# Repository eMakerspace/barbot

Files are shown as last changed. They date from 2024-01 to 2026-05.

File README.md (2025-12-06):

View this project on [CADLAB.io](https://cadlab.io/project/29307). 

# eMakerspace-BarBot

Design your own drinks...
- Use a WordPress configurator to design a drink
- Pay the drink with Twint
- Grab the data with a python script over the WooCommerce API
- Control the robot via the RPi HAT and make the drinks

## Web UI
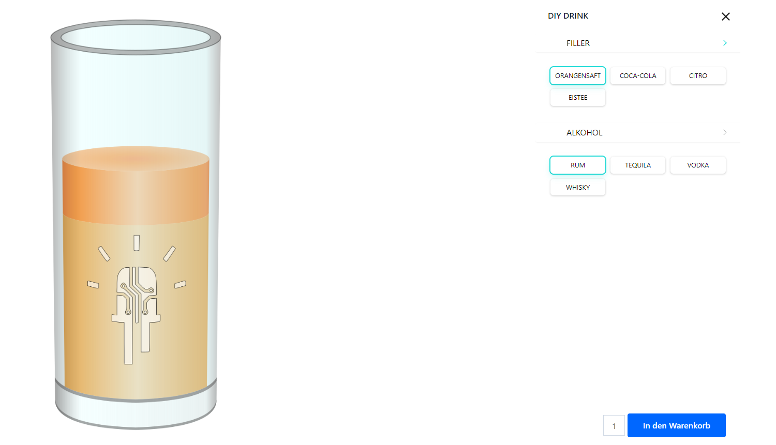
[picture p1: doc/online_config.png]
Configurator


## RPi HAT

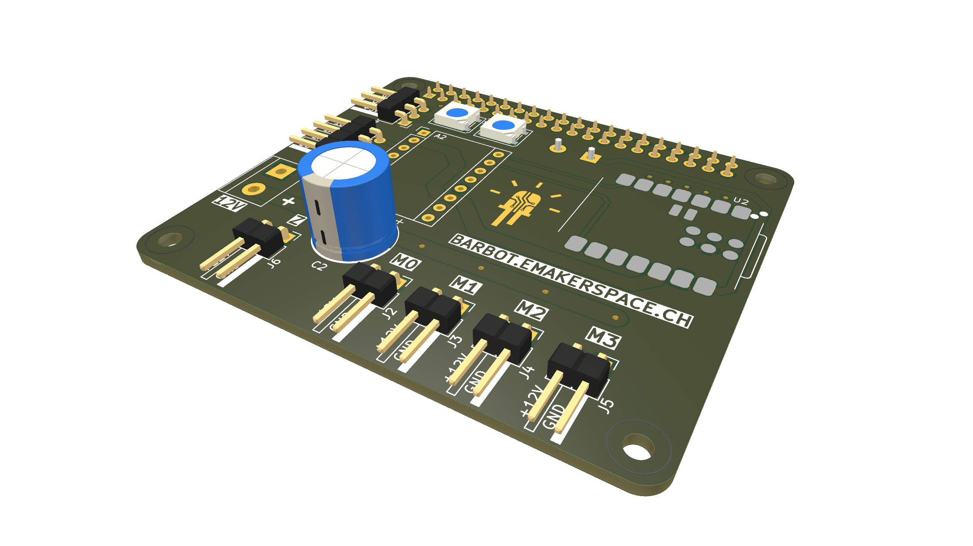
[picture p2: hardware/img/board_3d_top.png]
HAT


## Processing an order
```
━━━━━━━┳━━━━━━━━━━━━━━━━━━━━━━━━━━━━━━━┳━━━━━━━━━━━━━━
   444 ┃ Marco                         ┃ processing
━━━━━━━╋━━━━━━━━━━━━┳━━━━━━━━━━━━━━━━━━╋━━━━━━━━━━━━━━
    ID ┃ Name       ┃ Filler           ┃ Alc
───────╂────────────╂──────────────────╂──────────────
     0 ┃ Vodka-O    ┃ Orangensaft      ┃ Vodka
     1 ┃ DIY drink  ┃ Citro            ┃ Tequila

Process order 444
Process drink  0/1: Vodka-O
Robot: Waiting for a new cup
Robot: Start movement
Robot: Pouring filler: Orangensaft
Robot: Pouring alcohol: Vodka
Robot: Completed Vodka-O
Process drink  1/1: DIY drink
Robot: Waiting for a new cup
Robot: Start movement
Robot: Pouring filler: Citro
Robot: Pouring alcohol: Tequila
Robot: Completed DIY drink
Completed order 444, upload new status to WordPress
Upload completed
```

### Limitations
No umlauts allowed in the drinks

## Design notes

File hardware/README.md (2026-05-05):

# Modular Hardware

- Nothing is fixed; it will change anyway...
- Make a solid base for creative hacking
- Everything based on ribbon cable
- No free flying hardware and sketchy cables
- Every cable is keyed, no wrong polarities.

| &nbsp; | &nbsp; |
| --- | --- |
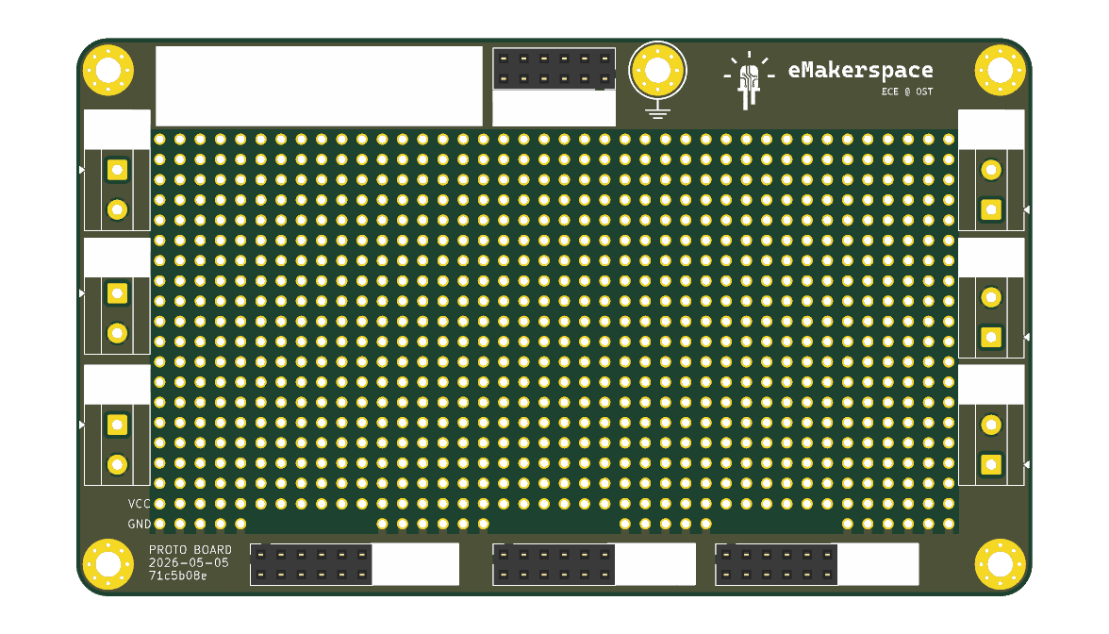
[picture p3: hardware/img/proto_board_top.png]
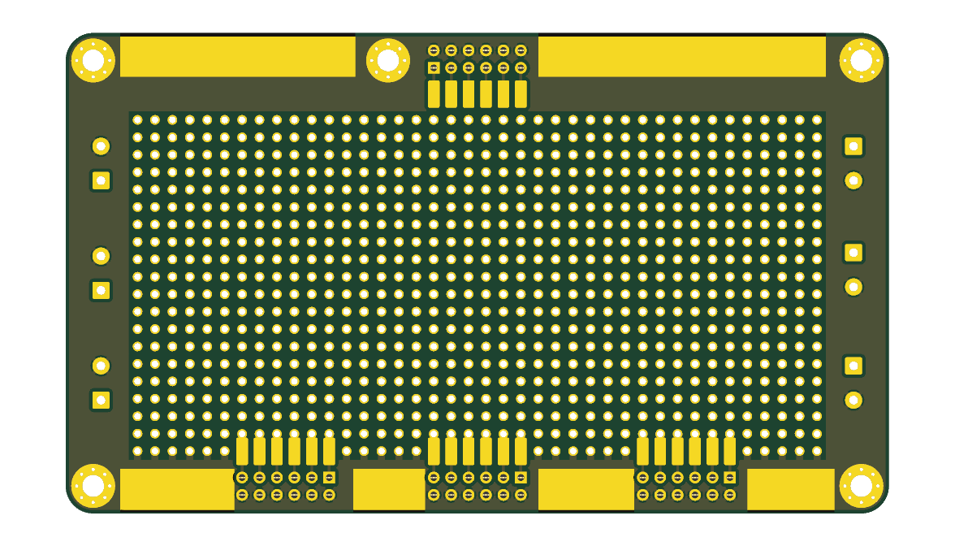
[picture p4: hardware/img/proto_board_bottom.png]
PCB Bottom
|  |  |
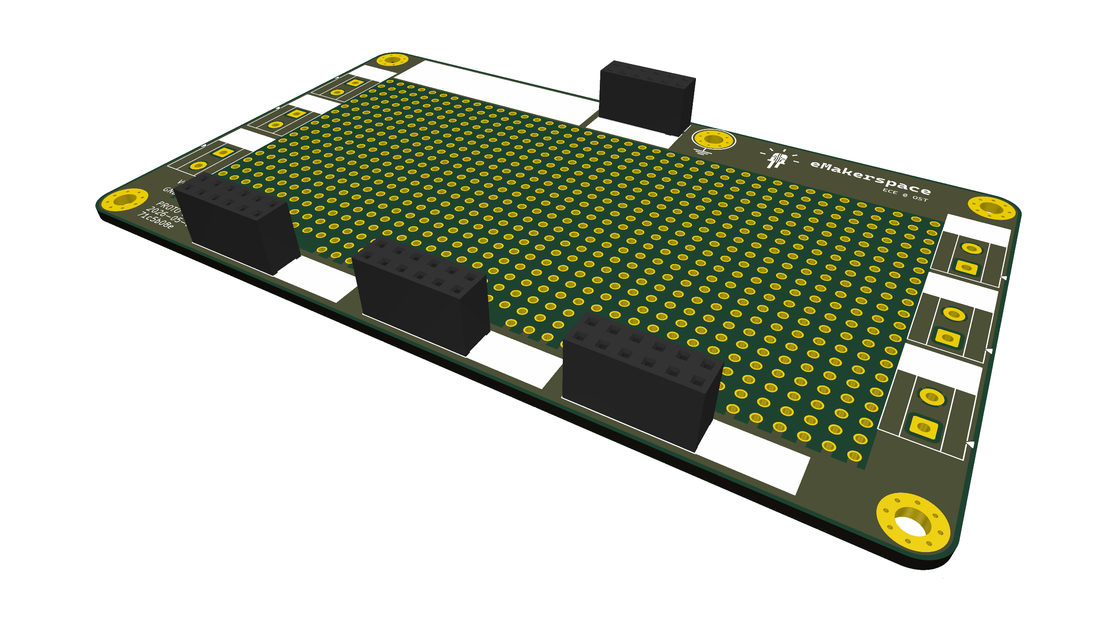
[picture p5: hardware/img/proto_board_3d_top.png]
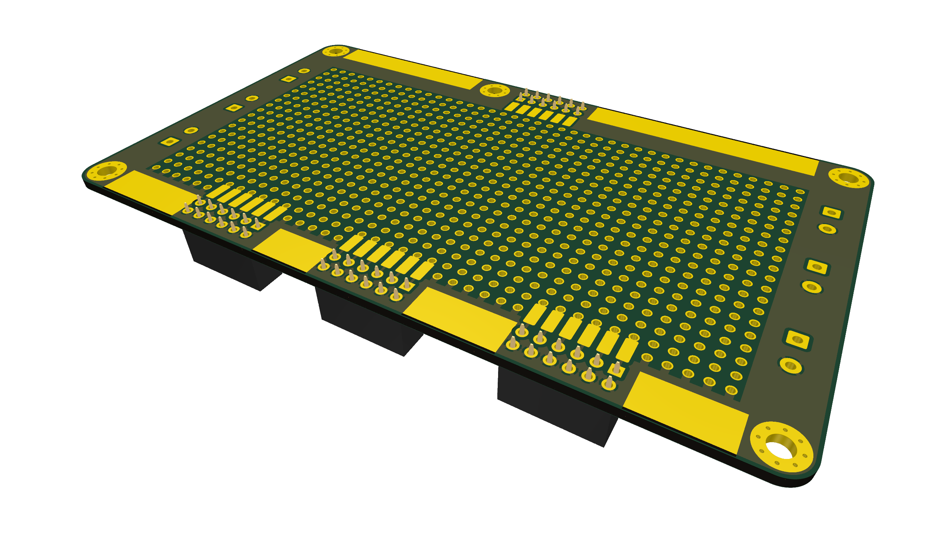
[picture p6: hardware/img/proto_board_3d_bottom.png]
PCB 3D Bottom
|  |  |

## Underling Architecture

- Different boards e.g.
    - IO
    - DC Motors with H-Bridge
    - Stepper motors
    - Proto board
    - Raspberry Pi
    - Main ESP



## BarBot HAT

First try with a fixed version, failed at the first adaption... ;-)

- Raspberry Pi HAT
- SEED Studio ESP32-C3
- One stepper motor driver
- Five 12V outputs, with a Tiny 1.5 A MOSFET Gate Driver
- Neopixel output

| &nbsp; | &nbsp; |
| --- | --- |
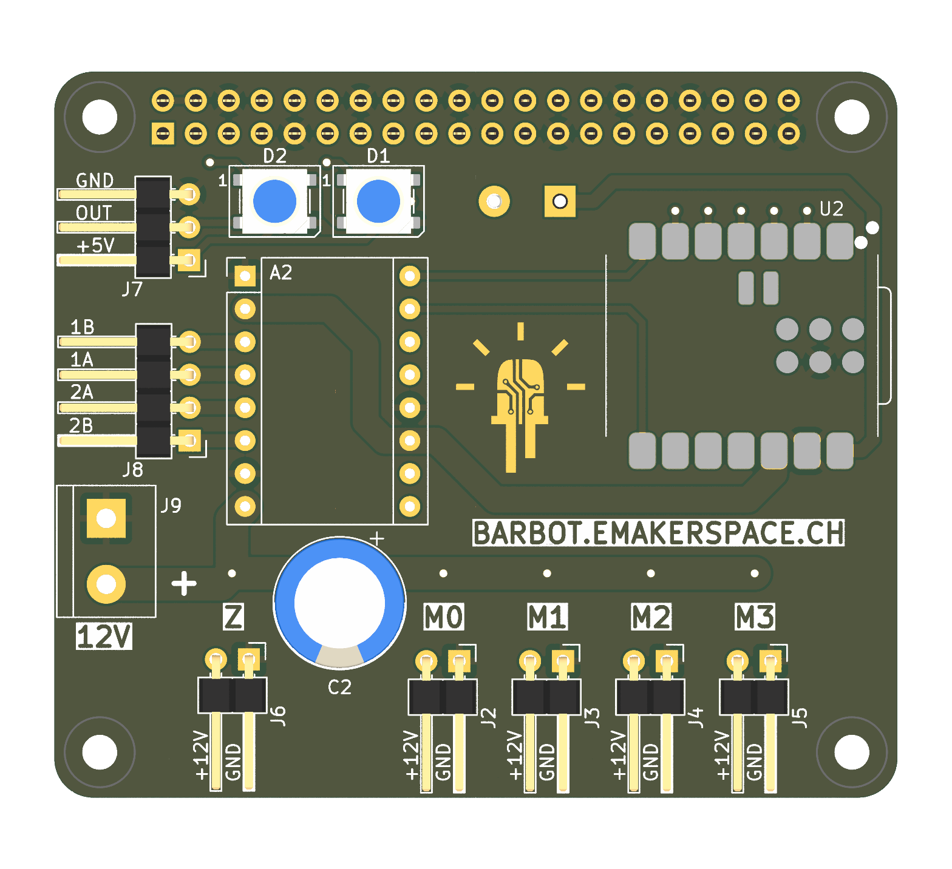
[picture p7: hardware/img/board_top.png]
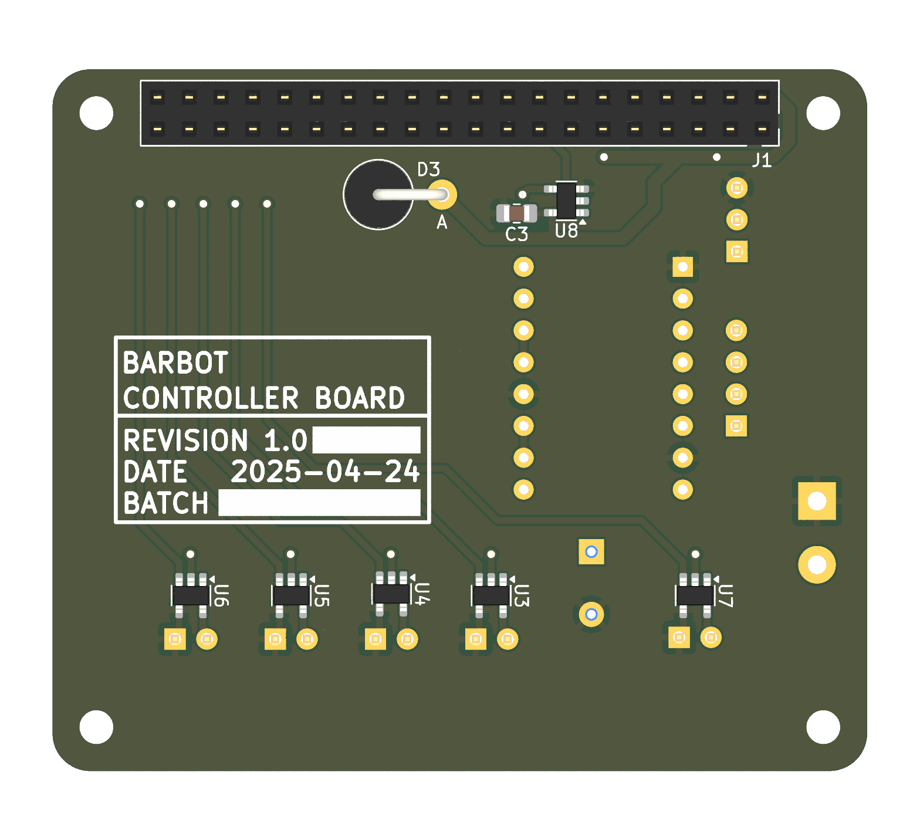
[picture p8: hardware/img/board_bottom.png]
PCB Bottom
|  |  |
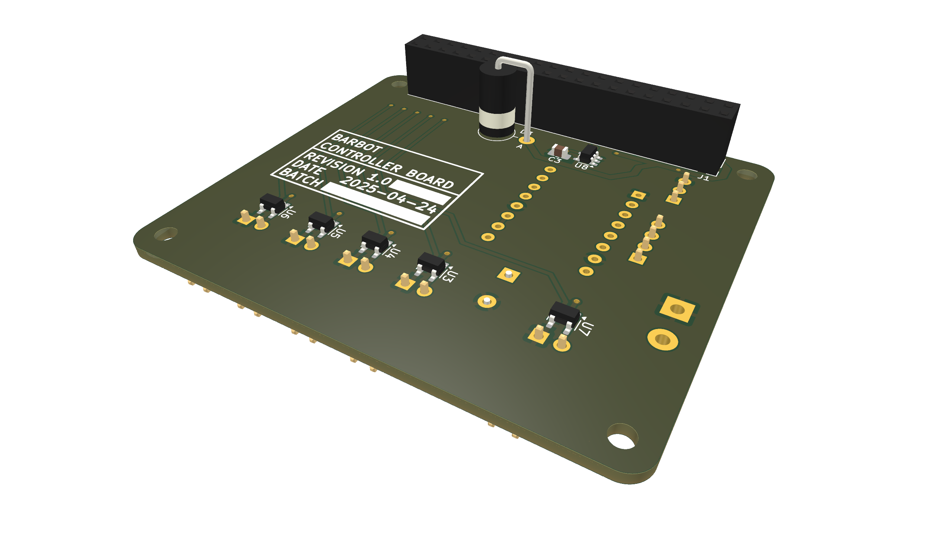
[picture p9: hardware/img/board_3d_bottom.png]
PCB 3D Bottom
| PCB 3D Top |  |

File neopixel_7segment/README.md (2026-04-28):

# 7-Segment + LED Strip Controller

**PlatformIO Project!!** open with Platform IO extension on VS Code.

ESP32-based controller for a two-digit 7-segment display and a chain of 87 NeoPixel LEDs split across three physically distinct segments.

## Hardware

| Component | Details |
|---|---|
| MCU | ESP32 DevKit v1 |
| Display | Two-digit 7-segment, multiplexed (common anode) |
| LED data pin | GPIO 13 |
| LED total | 87 WS2812 LEDs |

### LED segment layout

All three segments share one continuous data line in this order:

```
[0 … 42]   BAR   — 43 LEDs, horizontal bar
[43 … 58]  RING  — 16 LEDs, circular ring
[59 … 86]  U     — 28 LEDs, U-shape (left leg → bottom → right leg)
```

## Serial interface

Connect at **115200 baud**. Send commands as plain text lines terminated with `\n`.

### Commands

| Command | Description |
|---|---|
| `<number>` | Display a static number (0–99) on 7-segment |
| `-bl <number>` | Blink a number (0–99) on 7-segment |
| `-br <number>` | Breathing brightness effect on a number (0–99) on 7-segment |
| `-i` | Idle LED animations on all segments — **default mode on startup** |
| `-c` | Falling cup animation: 7-segment cup + vibrant flashing ring |
| `-mv` | Moving to slot: animates NeoPixel ring & segments, preserves 7-segment display |
| `-pour` | Pouring animation: animates NeoPixel ring & segments, preserves 7-segment display |
| `-mix` | Mixing animation: animates NeoPixel ring & segments, preserves 7-segment display |
| `-done` | Celebratory animation on NeoPixel (rainbow confetti burst + pulse cycle) |
| `-s` | Fast red strobe on all LEDs |
| `-drinkready` | Drink ready: green ring pulse + attention patterns on bar/U |
| `-drinknum <num>` | Drink ready with order number blinking on 7-segment |
| `-overduestrobe` | Overdue alert: full red strobe everything |
| `-e <effect>` | Error/status effect: `IDLE`, `RED_SOLID`, `RED_FLASH_FAST`, `RED_PULSE`, `YELLOW_SOLID`, `ORANGE_FLASH`, `GREEN_SOLID`, `GREEN_FLASH_SLOW`, `GREEN_FLASH_FAST` |

### Example session

```
42          → display shows 42 (static on 7-segment)
-bl 7       → display blinks 7 (7-segment only)
-br 55      → display breathes 55 (7-segment only)
-i          → all three LED segments start idle animations
-c          → falling cup on 7-segment + vibrant flash on ring
-mv         → animate ring/segments, keep previous 7-segment display
-done       → celebrate with rainbow confetti burst on NeoPixel
```

## Idle animations (`-i`)

All three segments animate **independently and simultaneously**. Each segment cycles through its own pool of effects, picking the next one at random when the current phase ends (20 s per phase by default, configured in `config.h`).

### BAR (LEDs 0–42)

| Effect | Description |
|---|---|
| Rainbow wave | Smooth hue gradient flows along the bar |
| Comet | Bright head races along the strip with a decaying white tail |
| Twinkle | Random pixels flash to random colours and fade |
| Breathing | Whole bar slowly breathes deep blue/cyan |
| Theater chase | Every-3rd-pixel chase with slowly rotating hue |
| Colour wipe | Fills pixel-by-pixel in red → green → blue, then clears |
| Scanner | KITT-style single pixel bounces back and forth |

### RING (LEDs 43–58)

| Effect | Description |
|---|---|
| Spin | A short arc of light rotates around the ring (1.5 s/rev) |
| Pulse | Whole ring breathes with a slowly cycling hue (2.5 s cycle) |
| Cylon | Single bright dot chases continuously around the ring with tail |

### U-SHAPE (LEDs 59–86)

| Effect | Description |
|---|---|
| Fill | Fills symmetrically from both tops toward the bottom, then clears |
| Bounce | Comet travels down the left leg, around the bottom, and up the right leg, then reverses |
| Meteor | Two meteors descend both legs simultaneously and meet at the base |

## Project structure

```
src/
  config.h               — all pin assignments, LED layout constants, timing
  main.cpp               — setup, loop, command dispatch
  SerialParser.{h,cpp}   — serial line reader and command parser
  DisplayController.{h,cpp} — 7-segment animation state machine
  SevenSegmentDriver.{h,cpp} — low-level multiplexed display driver (core 0)
  LedStripController.{h,cpp} — WS2812 animation engine (core 1)
  Fader.{h,cpp}          — brightness fader helper
```

## Building

```bash
pio run              # compile
pio run -t upload    # compile and flash
pio device monitor   # open serial monitor at 115200 baud
```

## Adding a new LED animation

1. Add `LED_DUR_<NAME>` in `config.h`
2. Append the duration to the appropriate `*_PHASES[]` array in `LedStripController.cpp`
3. Add a `case` in the matching `update*()` dispatcher
4. Implement `anim<Name>(uint32_t t)` — write only into your segment's index range

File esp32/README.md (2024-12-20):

# Barbot - ESP32

## Install libraries:
### Stepper
- Download library form https://www.airspayce.com/mikem/arduino/AccelStepper/
- Sketch -> Include library -> Add .ZIP Library...
- Then, select AccelStepper-1.64.zip

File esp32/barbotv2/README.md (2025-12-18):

# ESP32c3 firmware of barbot HAT

Uses Rust and [no-std esp-rs](https://docs.esp-rs.org/book/overview/using-the-core-library.html) crates for the firmware.
It is possible to simulate the esp32 firmware with
[Wokwi](https://docs.wokwi.com/?utm_source=wokwi), for this you must install the Wokwi
extension in vscode.

We use the [Seeed Studio XIAO esp32c3
board](https://www.seeedstudio.com/Seeed-XIAO-ESP32C3-p-5431.html).

## Pin Assignment

**4 Peristaltic Pumps**

- `PUMP_CTRL0`: `GPIO6`
- `PUMP_CTRL1`: `GPIO5`
- `PUMP_CTRL2`: `GPIO4`
- `PUMP_CTRL3`: `GPIO3`

[**Lift Motor**](https://www.adafruit.com/product/3190)
- `MOTOR_Z_UP`: `GPIO10` (PWM)
- `MOTOR_Z_DOWN`: `GPIO8` (PWM)

**Stepper Motor**
- `MOTOR_X_STEP`: `GPIO20` (PWM)
- `MOTOR_X_DIR`: `GPIO21`

**Misc**
- `End Switch`: `GPIO7` (active low)
- `Neopixel`: `GPIO2` (PWM)
- `Emergency Stop Switch`: `GPIO9` (active low)

## Installation

1. Install the Rust programmin language with [rustup](https://rustup.rs/).
2. Follow [this](https://docs.esp-rs.org/book/installation/riscv.html) to develop for esp32c3.

## Running

### Simulate

You need a Wokwi account, to be able to run simulations within vscode.

1. Activate the Wokwi extension license, press Ctrl-Shift-P and run `Wokwi: Request a New License`.
2. Select the right config, press Ctrl-Shift-P and run `Wokwi: Select Config File`.
3. Simulate with Wokwi, press Ctrl-Shift-P and run `Wokwi: Start Simulator`.

### Flash and Run

Run
```sh
cargo run
```
within a terminal in this directory.
This will run `espflash --monitor --chip <chip> <binary>`,
and should determine the right chip if it is connected with USB.

## Roadmap

- [X] Project setup, receiving commands, wokwi
- [X] Control stepper motor
- [X] Control pumps
- [X] Control lift motor
- [ ] Control LEDs
- [X] Stepper motor homing (with end-switch on `GPIO7`)
    - [X] Reacting to emergency stop (stops the stepper motor immediately).
- [X] G-code parsing, commands
    - [X] `G0 X{position}` for moving the stepper motor to step `{position}`.
    - [X] `G0.1 X{range_fact}` for moving the stepper motor to `range_fact * end_step`
          (where `end_step` is maximum step after homing). This allows specifying
          fractional positions within the homed range (`0` is the start, `1` is the end).
    - [X] `G1.0 Z{time_ms}` to move the lift motor down for `{time_ms}` milliseconds.
    - [X] `G1.1 Z{time_ms}` to move the lift motor up for `{time_ms}` milliseconds.
    - [X] `G2 I{pump} D{time_ms}` activate pump with index `{pump}` for duration `{time_ms}` milliseconds.
    - [X] `G2.1 I{pump} D{time_ms}` activate pump with index `{pump}` for `{time_ms}` milliseconds and wait
          for deactivation.
    - [X] `G28` to start homing.
    - [X] `T0 D{time_ms}` to wait for `{time_ms}` milliseconds.
    - [X] `M0` to stop the current command gracefully (and continue).
    - [X] `M0.1` to stop the current command immediately (emergency stop) and remain stopped until a `M1` command.
    - [X] `M1` recorvers from emergency stop.
    - [X] `M10` to toggle serial echo.

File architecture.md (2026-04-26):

# Barbot V2 System Analysis

## 1. Overall Architecture and Module Responsibilities

This is a Raspberry Pi-based automated bartender that integrates three microcontrollers via serial interfaces using G-code protocol.

### Hardware Architecture

| Controller | Role | Serial Port |
|---|---|---|
| **barbotv2 (HAT ESP32)** | Stepper motor (X-axis), servo (spirit optic), cup sensor | `/dev/serial/by-id/usb-Espressif_USB_JTAG_...` |
| **esp32_pump** | Peristaltic pumps (Slot_A–D), HX711 load cell, autonomous fill | `/dev/serial/by-id/usb-Silicon_Labs_CP2102...` |
| **Neopixel ESP32** | LED animations, 7-segment display | `/dev/serial/by-id/usb-1a86_USB_Serial...` |

### Module Organization

| Module | Responsibility |
|---|---|
| `config.py` | Configuration management (BarbotConfig, HardwareConfig, AttributesConfig, StoreConfig) |
| `hardware.py` | G-code serial driver (EspSerial, HardwareInterface) with dual ESP32 interfaces and IPC server |
| `lcd_menu.py` | Full-featured UI (4x20 LCD + rotary encoder) with state machine (13 modes) |
| `lcd.py` | Low-level I2C LCD wrapper (address 0x3F, PCF8574 backpack) with write-caching |
| `encoder.py` | Quadrature rotary encoder with 2 kHz polling and debounce (300 ms default) |
| `orders.py` | WooCommerce order polling and drink recipe processing |
| `mixer.py` | Recipe resolution (line_items → DrinkSpec with spirits + mixers) |
| `woo_client.py` | REST API wrapper with pagination and batch updates |
| `inventory.py` | Stock synchronization (push_all, sync_ingredient) |
| `store.py` | Product catalog caching and recipe derivation |
| `progress.py` | Crash-safe order progress tracking (disk-persisted JSON) |
| `console.py` | Legacy CLI (replaced by LCDMenu but still present) |
| `logger.py` | Unified logging with elapsed-time timestamps |
| `main.py` | Startup orchestration and signal handling |

---

## 2. Startup/Initialization Sequence

### main.py Flow (Lines 39–77)

```
1. init_missing_configs()
   → Creates default JSON files if missing

2. load_env()
   → Reads .env for WooCommerce credentials

3. Load all config objects
   → BarbotConfig (slot_mapping, poll_interval)
   → HardwareConfig (positions, timing, serial ports)
   → StoreConfig (cached products)
   → AttributesConfig (spirits/mixers/bottle_properties)

4. Initialize WooClient
   → REST API ready (timeout: 15s)

5. Initialize HardwareInterface
   → Open HAT serial port (115200 baud)
   → Open Pump serial port (115200 baud)
   → Open Neopixel serial port (115200 baud)
   → Start IPC server on /tmp/barbot.sock

6. Create InventoryManager
   → Stock tracking and WooCommerce sync

7. Create OrderProcessor
   → Order fetching and execution

8. Create LCDMenu (UI entry point)
   → Inject UI reference into OrderProcessor and HardwareInterface

9. Execute homing sequence (blocking)
   → Servo parked at close_angle (180°) BEFORE stepper homes
   → Safety-critical ordering

10. Background daemon thread
    → Fetches WooCommerce attributes and products
    → Errors swallowed; user can re-fetch from Setup menu

11. Enter main render loop (50 ms iterations)
```

---

## 3. Main Event Loop and State Machine

### LCDMenu States (13 Distinct Modes)

| Mode | Purpose | Transitions |
|---|---|---|
| `menu` | Navigate Setup/Run/Maintenance menus | Rotate to scroll, press to select |
| `run` | Order polling loop active | Backlight timeout, error → pause |
| `info` | Display-only info screen | Auto or button to return |
| `working` | Task execution (homing, fetch, teach) | Spinner until `_work_done` flag |
| `confirm` | Yes/No dialog | Rotate to toggle, press to confirm |
| `mixing` | Show drink number during dispensing | Auto-dismiss when `_cup_present == False` |
| `cup_removed` | Brief 2 s confirmation | Auto-dismiss |
| `add_cup` | Flashing "PUT CUP IN!" prompt | Auto-dismiss when cup detected |
| `error` | Error display with RETRY/CANCEL | Rotate to select, press to confirm |
| `visc_edit` | Adjust viscosity per ingredient | Rotate to adjust, press to save |
| `x_move` | Jog stepper to position | Rotate L/R, press to confirm |
| `teach` | Jog stepper + save slot position | Rotate L/R, press to save |
| `num_entry` | Generic integer input | Rotate to increment, press to confirm |
| `pin_lock` | PIN code entry (feature-gated) | Digit input with timeout |

### Render Loop (Lines 709–732)

```
Every 50 ms:
  1. Acquire _lock
  2. Dispatch to mode-specific draw method
  3. Release _lock
  4. Write changed rows to LCD (cache prevents flicker)
```

### Input Flow

**Encoder (RotaryEncoder, daemon thread at 2 kHz)**
- Quadrature state machine with transition table
- Accumulates at ±STEPS_PER_DETENT (default: 4)
- Calls `_on_rotate(direction)` when detent crossed
- Calls `_on_press()` when button pressed (debounce: 300 ms)
- All callbacks acquire `_lock` before modifying state

**Critical Threading Note**: Encoder callbacks run in HAL thread, not main thread. All state mutations must be atomic under `_lock`.

---

## 4. All Execution Paths (Normal, Error, Edge Cases)

### A. Order Processing Path

```python
process_order(order_dict):
    1. resolver.resolve(line_items) → DrinkSpec[] (spirits + mixers)
    2. OrderProgress.resume_from_disk() → skip completed drinks on crash
    3. Spawn heartbeat thread (15 s interval, WooCommerce keep-alive)
    4. hw.display_order_id(order_id % 100) → show breathing number on 7-seg
    
    For each drink:
        ui.show_mixing(drink_num, total, name)
        hw.make_drink(spec)  ← Full drink every time (no mixers-only retry)
        progress.drink_done() → write to disk
    
    On exception:
        ui.clear_mixing()
        Raise (order moves to error state with RETRY/CANCEL options)
    
    On success:
        progress.drink_done() → delete file
        woo.update_order_status(order_id, "completed")
```

### B. Drink Dispensing Path

```python
make_drink(spec):
    1. wait_for_cup() → blocks until cup detected via serial
    2. Show breathing animation on 7-seg display
    
    3. For each spirit in spec.spirits:
        dispense_spirit(slot, pours, viscosity):
            - move_to_idle() → servo at close_angle
            - move_x(position) → blocks until "Move done"
            - For each pour:
                - Open servo → wait pour_ms → close → wait settle_ms
                - Update 7-seg breathing animation
    
    4. For each mixer in spec.mixers:
        dispense_mixer(slot, ml):
            - move_x(position) → wait "Move done"
            - tare_scale() → zero load cell
            - G4 I{pump} W{weight} → autonomous fill until target weight
            - Wait for [FILL_END] response (raise HardwareError if timeout/low_weight)
            - Update 7-seg breathing animation
    
    5. move_to_idle() → safe position with servo closed
    6. Send "-done" to neopixel for celebration animation
    
    7. wait_for_cup_removal(timeout=300s):
        - Phase 1 (0–60 s): Green ring pulse + breathing order ID on 7-seg
        - Phase 2 (60 s+): Red strobe + "Take your drink!" LCD error
        - After timeout: logs warning but continues (does NOT raise)
```

### C. Cup Detection & Removal

**wait_for_cup()** (hardware.py:521-568)
- Blocks on `_cup_state_changed.wait(timeout=30)` event
- ESP32 reports `[cup] PRESENT` / `[cup] ABSENT` via serial
- Timeout: 30 s → raises `HardwareError` ("Cup detection timed out")
- On detection: triggers no UI change (already in mixing mode), returns immediately

**wait_for_cup_removal()** (hardware.py:594-657)
- Called after drink is complete to ensure cup is physically taken
- Shows "cup_removed" UI mode (2-3 line message)
- Sends `-drinkready` animation to neopixel (green + order ID)
- Phase 1 (0–60s): Cup removal alert with escalating blink speed
- Phase 2 (60s+): `-overduestrobe` (red) + `show_error("Take your drink!", 2)` UI alert
- **Does NOT raise on timeout after 300s** → logs warning and continues
- This allows system to proceed to next order even if customer didn't collect

### D. Error Handling Path

**Hardware Exception in make_drink()** (orders.py:100-104)
- Any exception during `process_order()` is caught and logged
- `pause_polling(error_name)` is called, which:
  - Sets `_polling_paused = True`
  - Switches UI to 'error' mode with RETRY/CANCEL selector
  - Turns on LCD backlight
  - Pauses polling loop (stops fetching orders)

**User Response to Error** (lcd_menu.py:465–582)
- Encoder rotation: toggle between RETRY and CANCEL
- Button press confirms selection:
  - **RETRY**: Resume polling, re-fetch orders, make entire drink again
  - **CANCEL**: Call `orders.skip_current_drink()` (advance progress), resume polling

**Neopixel LED Status**
- Breathing order ID: `-br {num}` (while making drink)
- Celebration: `-done` (when drink complete)
- Drink ready: `-drinkready` (start cup removal phase)
- Overdue strobe: `-overduestrobe` (if cup not taken after 60s)
- Fast blink: `-bl {num}` (overdue state on 7-seg)

---

## 5. Threading Model and Concurrency Risks

### Thread Architecture

| Thread | Role | Daemon | Lock | Risk Level |
|---|---|---|---|---|
| Main | 50 ms render loop | No | `_lock` | Low |
| Encoder HAL | 2 kHz quadrature + button (RotaryEncoder) | Yes | `_lock` | Medium |
| Serial reader (HAT) | Read lines, enqueue, trigger callbacks | Yes | None | High |
| Serial reader (pump) | Read lines, enqueue, trigger callbacks | Yes | None | High |
| Order polling | Fetch + process_order() (blocking) | Yes | None | Medium |
| Heartbeat | WooCommerce ping (15 s) | Yes | None | Low |
| Working task | Homing, fetch, etc. (short blocking) | Yes | None | Low |
| IPC server | Accept `/tmp/barbot.sock` connections | Yes | None | Low |

### Concurrency Risks

#### CRITICAL: Unprotected Serial Callbacks

**Files**: hardware.py:384–392, 397–406, 453–460

Callbacks `_on_cup_state()`, `_on_error_state()`, `_on_calibrated()` are called from the serial reader thread **without acquiring `_lock`**. They modify:
- `_cup_present` (boolean)
- `_cup_state_changed.set()` (threading.Event)
- Trigger callback invocations

**Mitigation**: CPython guarantees atomic boolean assignment and Event.set() is thread-safe. However, this is not a formal language guarantee and is fragile.

**Risk**: If UI thread reads `_cup_present` while serial thread writes, possible stale read (unlikely but possible).

#### HIGH: Unbounded Queue in EspSerial

**File**: hardware.py:148 (wait_for method)

```python
if line not in self.queue.queue:
    self.queue.put(line)
```

Queue has no maximum depth. If serial reader enqueues faster than consumers dequeue, memory grows unbounded.

**Likelihood**: Very low (serial is slow, consumers block). **Severity**: Memory leak if triggered.

#### MEDIUM: _sync() Barrier Race

**Files**: hardware.py:775–797

`_sync()` sends `G0 X{current_pos}` as no-op to serialize the command queue. If another thread sends a command before `_sync()` finishes waiting, ordering is violated.

**Example**: Polling thread calls `dispense_spirit()`, which calls `move_x()` + `_sync()`. Meanwhile, emergency stop is triggered, which sends `M0.1` before `_sync()` completes.

**Mitigation**: `_sync()` is always called serially from dispense operations (not interleaved). Risk is low in practice.

#### MEDIUM: Polling Pause Flag Race

**File**: lcd_menu.py:1764–1769

`_polling_paused` and `_retry_drink` are checked without `_lock` in the polling loop:

```python
while not stop.wait(self.hw.poll_interval):
    if self._polling_paused:
        ...
```

**Severity**: Low (bool read is atomic, worst case off-by-one poll cycle).

#### LOW: LCD Write Cache Not Locked

**Files**: lcd.py:55–70

`_write_row()` reads `_cache` without lock. Render loop holds `_lock` but `_write_row()` itself is unprotected.

**Severity**: Medium (write cache is per-row, unlikely collision, worst case temporary flicker).

---

## 6. Hardware Interaction (GPIO, I2C, Serial)

### GPIO Setup

```python
GPIO.setmode(GPIO.BCM)
GPIO.setwarnings(False)
```

### Encoder Pins (RotaryEncoder)

| Pin | GPIO | Function |
|---|---|---|
| CLK | BCM 27 | Quadrature A |
| DT | BCM 17 | Quadrature B |
| SW | BCM 22 | Button (pull-up configured) |

### I2C LCD

- Address: `0x3F` (PCF8574 backpack)
- Bus: 1 (default Raspberry Pi I2C)
- Display: 20×4 character (RPLCD library)

### Serial Interfaces (All 115200 baud, 0.1 s timeout)

1. **HAT Serial** (barbotv2 ESP32)
   - Device: `/dev/serial/by-id/usb-Espressif_USB_JTAG_...`
   - Commands: G-code motion, servo, cup detection

2. **Pump Serial** (esp32_pump)
   - Device: `/dev/serial/by-id/usb-Silicon_Labs_CP2102...`
   - Commands: Pump control, scale tare/calibration, autonomous fill

3. **Neopixel Serial** (LED ESP32)
   - Device: `/dev/serial/by-id/usb-1a86_USB_Serial...`
   - Commands: Fire-and-forget LED animations (no response reading)

---

## 7. G-code Command Reference

### Motion Commands

| Command | Effect | Response | Notes |
|---|---|---|---|
| `G28` | Home stepper (calibrate X=0) | `"Homing successful, end pos = N"` | Safety-critical: servo must be closed first |
| `G0 X{n}` | Move to absolute position (0–6000) | `"Move done"` | Blocking, waits for carriage arrival |
| `G0.1 X{f}` | Fractional move (0.0–1.0) | `"Move done"` | Useful for soft positioning |
| `G1 Z{angle}` | Servo to angle (0–180°) | *(none)* | Immediate; no wait for servo arrival |
| `G5 P{p4} Q{p5}` | Set forbidden zones | *(none)* | Prevents servo opening in collision areas |
| `T0 D{ms}` | Delay (blocking) | *(none)* | Used for pour timing |
| `M0` | Graceful stop | *(none)* | Finish current command, then stop |
| `M0.1` | Emergency stop | *(none)* | Stop immediately (unsafe) |
| `M1` | Resume after stop | *(none)* | |

### Pump & Scale Commands

| Command | Effect | Response | Notes |
|---|---|---|---|
| `G2 I{n} D{ms}` | Run pump n for ms (non-blocking) | *(none)* | Pump returns to idle after ms |
| `G2.1 I{n} D{ms}` | Run pump n for ms (blocking) | *(none)* | Waits for pump to complete |
| `G3` | Read scale weight | `"Weight: X.XXg (raw: ...)"` | Used for testing scale |
| `G3.1` | Tare scale (zero offset) | `"Scale tared (offset: ...)"` | Must be called before fill |
| `G3.2 W{g}` | Calibrate with known weight | `"Calibrated: X.XXX counts/gram"` | Saved to hardware_config.json |
| `G3.3 F{cpg}` | Restore calibration factor | *(none)* | Loaded from disk on startup |
| `G4 I{n} W{g}` | Autonomous fill pump n to g grams | `[FILL_END] reason=... dispensed=...g` | Non-blocking on HAT; ESP32 handles timeout |

### Response Patterns

- `[cup] PRESENT` / `[cup] ABSENT` — Cup state change
- `[ERROR_STATE] code=N name=... effect=... severity=...` — Hardware error
- `[FILL_END] reason=target_reached` — Successful fill
- `[FILL_END] reason=timeout` — Fill timeout (HardwareError)
- `[FILL_END] reason=low_weight` — Scale reading too low (HardwareError)

---

## 8. WooCommerce/Network Integration

### WooClient (woo_client.py)

**Initialization**:
- Endpoint: `WOOCOMMERCE_URL` from `.env`
- Auth: `WOOCOMMERCE_KEY`, `WOOCOMMERCE_SECRET`
- Timeout: 15 s
- Library: `woocommerce.API` (python-woocommerce)

**Methods**:

| Method | Endpoint | Behavior |
|---|---|---|
| `fetch_all(endpoint, params)` | GET with pagination | Auto-pagination (100 per page), silently breaks on error |
| `batch_update_products(updates)` | POST `/products/batch` | Updates multiple products |
| `batch_update_variations(product_id, updates)` | POST `/products/{id}/variations/batch` | Updates variants |
| `update_order_status(order_id, status, retries=3)` | PUT `/orders/{id}` | Retries 3× with 2 s delay, silently fails on final retry |
| `send_heartbeat()` | POST `/wp-json/barmachine/v1/ping` | Custom endpoint, errors logged but ignored |
| `update_term_viscosity(attr_id, term_id, viscosity)` | PUT `/products/attributes/{id}/terms/{id}` | Updates ingredient viscosity |

### Order Polling Loop (lcd_menu.py:1706-1742)

```python
_poll() daemon thread (in run mode):
    loop:
        1. woo.send_heartbeat()
        2. Check _polling_paused flag
        3. If paused:
            - sleep(1s) and continue (waiting for user RETRY/CANCEL)
        4. Otherwise: Fetch all 'processing' orders
        5. For each order (sorted by ID):
            try:
                process_order(order) ← Makes FULL drink every time (no retry_mixers_only)
                _run_count += 1
            except Exception:
                pause_polling(error_name[:20])
                break  ← Exit polling loop, wait for user action
        6. stop.wait(poll_interval) → sleep until next poll
```

**Polling Behavior**:
- When an error occurs, `_polling_paused` is set and loop stops fetching
- UI shows error mode with RETRY/CANCEL selector
- User can toggle with encoder, confirm with button:
  - **RETRY**: Clears `_polling_paused`, resumes polling, will re-fetch and make the full order again
  - **CANCEL**: Calls `orders.skip_current_drink()` to advance progress past failed drink, resumes polling

**Poll Interval**: 5 s (from config.poll_interval)

### Heartbeat Thread (orders.py:73–81)

```python
heartbeat_thread(every 15 s during order processing):
    while order_processing:
        woo.send_heartbeat()
        sleep(15s)
```

Purpose: Notify WooCommerce that barbot is still working on the order (prevents re-polling).

### Inventory Sync (inventory.py)

| Method | Effect |
|---|---|
| `push_all()` | Sync all products/variations: mark in/out of stock based on mounted ingredients |
| `sync_ingredient(ingredient, in_stock)` | Find all products using this ingredient, toggle stock status |

---

## 9. All Possible System States

### Application Level

| State | Condition | Actions |
|---|---|---|
| **Startup** | Loading configs, initializing hardware, homing | Spinner on LCD |
| **Menu** | Idle, user navigating | Rotate/press encoder |
| **Setup** | Configuring slots, fetching store, managing viscosity | Menu navigation |
| **Run** | Polling WooCommerce for orders | Backlight timeout active |
| **Error** | Hardware or WooCommerce error occurred | Show RETRY/CANCEL selector |
| **Mixing** | Dispensing drink | Show drink number, progress bar |
| **Shutdown** | Graceful Ctrl+C or quit | Signal handlers, cleanup |

### Hardware States

| Component | States |
|---|---|
| **X-axis Stepper** | Homing, idle at home (0), idle at slot (500–6000), moving between positions |
| **Servo** | Closed (180°), pouring (85°), forbidden zone (blocked) |
| **Cup Sensor** | ABSENT, PRESENT, unknown (pre-detection) |
| **Pumps A–D** | Idle, running timed (G2), autonomous fill (G4) |
| **Scale** | Unzeroed, zeroed (tared), reading weight |

### Order States

| State | Location | Behavior |
|---|---|---|
| **Polling** | WooCommerce | Fetching 'processing' orders |
| **Processing** | Local queue | Heartbeat running, making drinks |
| **Paused** | UI (RETRY/CANCEL) | User chooses action |
| **Completed** | WooCommerce | Status updated to "completed", cleared from queue |
| **On-Hold** | WooCommerce | Order error occurred, no re-poll (prevents loop) |

---

## 10. Error Sources and Failure Modes

### A. Hardware Failures

#### Serial Port Unavailable
- **File**: hardware.py:__init__
- **Detection**: Exception on `serial.Serial(port, 115200)`
- **Response**: Runtime error
- **Impact**: UI shows warning banner (lines 592–635), no real hardware interaction

#### Cup Sensor Timeout
- **File**: hardware.py:562–568
- **Detection**: `wait_for_cup()` blocks > 30 s
- **Response**: Raise `HardwareError`
- **Caught by**: `process_order()` exception handler
- **Impact**: Order moved to "on-hold", LED shows RED_FLASH_FAST

#### Homing Failure
- **File**: hardware.py:687–694
- **Detection**: G28 response doesn't contain "Homing successful"
- **Response**: Raise `HardwareError`
- **Caught by**: `_wait_work()` in LCD menu
- **Impact**: UI shows error, user can retry homing

#### Move Timeout
- **File**: hardware.py:742–743
- **Detection**: `_sync()` times out waiting for "Move done"
- **Response**: Log warning, **continue anyway**
- **Impact**: If carriage hasn't finished moving, next pour starts in transit (dangerous!)

#### Servo Forbidden Zone Violation
- **File**: hardware.py:854–856
- **Detection**: `in_forbidden_servo_zone()` returns True
- **Response**: Print warning, **return without pouring**
- **Impact**: Drink served incomplete with NO LCD indication to user

#### Pump Fill Failure
- **File**: hardware.py:915–918
- **Detection**: `[FILL_END] reason != "target_reached"`
- **Response**: Raise `HardwareError`
- **Caught by**: `process_order()` exception handler
- **Impact**: Order moved to "on-hold", user can RETRY (retry_mixers_only=True)

#### Scale Not Detected
- **File**: hardware.py:934–937
- **Detection**: G3.1 response contains "HX711 not"
- **Response**: Raise `HardwareError`
- **Impact**: Tare operation fails, autonomous fill unavailable

#### Calibration Loss
- **File**: hardware.py:432–453
- **Restoration**: Factor persisted to hardware_config.json
- **Fallback**: On restart, G3.3 restores factor; if file missing, firmware default used

### B. Network Failures

#### WooCommerce Unreachable
- **File**: woo_client.py:fetch_all
- **Detection**: Exception during HTTP request
- **Response**: Log error, return empty list `[]`
- **Caught by**: `_poll()` in lcd_menu.py
- **Impact**: No orders fetched, poll loop sleeps and retries (no alerting to user)

#### Order Status Update Fails
- **File**: woo_client.py:122–136
- **Detection**: HTTP error after 3 retries (2 s delay each)
- **Response**: Log error, **silently give up**
- **Critical Issue**: Order remains "processing" in WooCommerce
- **Impact**: Order re-polled on next cycle, same drinks made twice (idempotency violation!)

#### Heartbeat Timeout
- **File**: orders.py:75–78
- **Detection**: Exception during heartbeat send
- **Response**: Log warning, **continue**
- **Impact**: Website may timeout waiting for order completion

### C. Configuration Errors

#### Missing hardware_config.json
- **File**: main.py:77–81
- **Detection**: FileNotFoundError from load_json
- **Response**: Raise, application exits during startup
- **Impact**: Barbot completely non-functional

#### Invalid Slot Position
- **File**: hardware.py:position_for_slot
- **Detection**: Slot not found in config
- **Response**: Return `None`
- **Caught by**: `dispense_spirit()` / `dispense_mixer()`
- **Impact**: HardwareError raised, order on-hold

#### Ingredient Not in Mounted Slots
- **File**: hardware.py:1047–1048
- **Detection**: Drink spec has `slot=None`
- **Response**: Print warning, **skip pouring**
- **Impact**: Incomplete drink served silently (no LCD indication)

### D. UI/Input Failures

#### Encoder I2C Failure
- **File**: lcd_menu.py:235–243
- **Detection**: Exception from RotaryEncoder.start()
- **Response**: Try to display error on LCD, then raise
- **Impact**: UI non-functional, user can't interact

#### LCD I2C Failure
- **File**: lcd.py (RPLCD calls)
- **Detection**: Exception from write_row()
- **Response**: Propagates to _render()
- **Impact**: Render loop crashes, UI updates stop

#### Button Debounce Mismatch
- **File**: encoder.py:66
- **Debounce**: 300 ms default
- **Issue**: Very fast button presses (< 300 ms) skipped
- **Impact**: UI may not respond to rapid input

### E. Data Corruption Risks

#### Order Progress File Corruption
- **File**: progress.py (OrderProgress)
- **Corruption Scenario**: File truncated mid-write due to crash
- **Behavior**: `resume_from_disk()` catches JSONDecodeError, returns 0 (all drinks re-made)
- **Mitigation**: None (no atomic write or backup)

#### Config File Write Not Atomic
- **File**: config.py:save_json
- **Mechanism**: Direct overwrite (no tempfile + rename)
- **Scenario**: Crash mid-write leaves file partially written
- **Mitigation**: load_json catches FileNotFoundError, but JSONDecodeError will crash

#### Slot Mapping Changed During Poll
- **File**: config.py (BarbotConfig.slot_mapping)
- **Scenario**: Menu saves new mapping to disk while polling loop reads it
- **Mitigation**: Dict reference swap is atomic on CPython (CPython-specific guarantee, not language guarantee)

---

## 11. Critical Bugs and Race Conditions

### 1. **DESIGN: Cup Removal Timeout Does Not Raise (Intentional)**

**File**: hardware.py:594-657 (wait_for_cup_removal)

**Behavior**:
```python
def wait_for_cup_removal(self, timeout_sec=300):
    # Phase 1 (0–60s): green animations
    # Phase 2 (60s+): red strobe + LCD error
    # After timeout: log warning and return (do NOT raise)
```

**Rationale**: 
- If a customer forgets to take their drink, the system should not get stuck
- `wait_for_cup_removal()` runs after every drink and blocks until cup is taken OR timeout expires
- Timeout set to 5 minutes (300s), with overdue escalation at CUP_REMOVAL_OVERDUE_SEC (60s)
- On timeout, LED animations stop and system is ready for next order
- **Design intent**: Unattended operation (e.g., nightclub events) where customers may forget to collect immediately

**Potential Issue**:
- If the next order arrives very quickly (polling interval is 5s), system might still have `_cup_present=True` from previous order
- `wait_for_cup()` would return immediately without blocking
- **Mitigation**: Cup sensor must transition ABSENT → PRESENT for new cup detection to work correctly
  - System relies on physical cup removal to clear sensor state

---

### 2. **LIMITATION: Retry Logic Simplified (Full Drink, Not Mixers-Only)**

**File**: lcd_menu.py:578-582, orders.py:59-112

**Current Behavior** (as of commit f170055):
- When error occurs during order processing, user sees RETRY/CANCEL selector
- **RETRY**: Full drink is made again from scratch (cup detection → spirits → mixers)
- **CANCEL**: `skip_current_drink()` advances progress, order resumes from next drink

**Previous Behavior** (commit f170055~1):
- RETRY would skip cup detection and spirits, only re-dispense mixers
- This was an optimization to avoid re-detecting cups and re-pouring spirits if only pumps failed

**Why Changed**:
- Simplified logic: full drink retry avoids state complexity
- If a spirit fails, retrying mixers-only would dispense mixer into a drink lacking spirit (wrong)
- Better UX: RETRY is clear and predictable; CANCEL skips entirely

**Trade-off**:
- More robust: No partial-drink states
- Less efficient: If pump failure, spirits are re-poured unnecessarily
- Still safe: ErrorProgress tracks completed drinks, never repeats a full order

---

### 3. **DESIGN: Forbidden Zone Handling (Implementation Specific)**

**File**: hardware.py (dispense_spirit method)

**Behavior**: 
- Forbidden zones are set via `G5 P{p4} Q{p5}` to protect servo from hitting carriage
- System uses `in_forbidden_servo_zone(position)` check before pouring

**Current State**: Check implementation and fallback behavior depend on HardwareInterface configuration. If a slot is in forbidden zone, system either:
1. Raises HardwareError (pauses order), or
2. Skips pour silently with warning log

**Note**: Forbidden zones should be configured during setup (`_do_teach_forbidden_zone`) to ensure all mountable slots are accessible.

---

### 4. **REMOVED: Mixers-Only Retry Path (Simplified as of f170055)**

**File**: Previously lcd_menu.py:1713-1728, orders.py (legacy)

**What Was Removed**:
- Separate retry logic that only re-dispensed mixers (pumps) after spirit failure
- Required complex state tracking (which drink/spirits done, which mixers remaining)
- Risk: mixer retried into drink lacking spirit (wrong result)

**Replacement**:
- User sees RETRY/CANCEL on error
- RETRY: Makes entire drink from scratch (cup → spirits → mixers)
- CANCEL: Skips drink, moves to next one
- OrderProgress.resume_from_disk() prevents duplicating completed drinks on crash

---

### 5. **MEDIUM: Unprotected `_cup_present` Read/Write Across Threads**

**File**: hardware.py:384–392 (_on_cup_state_changed callback)

**Code**:
```python
def _on_cup_state_changed(self, *args):
    self._cup_present = "PRESENT" in msg  # ← No lock
    self._cup_state_changed.set()
```

**Problem**:
- Serial reader thread writes `_cup_present` without lock
- Main thread (render loop) reads `_cup_present` under `_lock`
- Polling thread reads `_cup_present` from `wait_for_cup()`
- **Race**: Serial write and main read can occur simultaneously

**Severity**: Low in practice (CPython atomic assignment), but not formally guaranteed.

**Mitigation**: `threading.Event` (.set() and .wait()) are thread-safe primitives. Boolean assignments are atomic on CPython.

**Better Fix**: Acquire lock in callback, or use `Queue` for state updates.

---

### 6. **MEDIUM: `_sync()` Timeout Continues Silently**

**File**: hardware.py:742–743

**Code**:
```python
if not self._sync(timeout=30):
    logger.warning(f"_sync() timed out; assuming move complete")
    # Continue anyway ← dangerous if move still in progress
```

**Problem**:
- If carriage move times out (> 30 s), function continues
- If carriage hasn't actually finished moving, next command proceeds while carriage in transit
- **Result**: Pumps dispensing while carriage moving, servo potentially in collision zone

**Scenario**:
1. `dispense_spirit()` called
2. `move_x(position)` enqueued
3. Carriage moves slowly (mechanical jam?)
4. `_sync()` times out after 30 s
5. Function continues to _pour_sequence()
6. Servo opens, pumps run **while carriage still moving**
7. Collision or incorrect pour location

**Fix**: Raise `HardwareError` on `_sync()` timeout, don't continue.

---

### 7. **MEDIUM: Polling Loop Stuck on Exception**

**File**: lcd_menu.py:1801–1804

**Code**:
```python
try:
    self.processor.process_order(order)
except Exception as e:
    logger.error(f"Error processing order: {e}")
    self.pause_polling()
    break  # ← Exits polling loop
```

**Problem**:
- If `process_order()` raises, polling loop breaks
- No more orders processed until user presses button (RETRY/CANCEL)
- If UI not responsive or user not present, machine is stuck

**Scenario**:
1. Unknown exception in `process_order()` (not HardwareError)
2. Polling loop breaks
3. User needs to see error and press RETRY
4. If running "headless" (no display), machine stuck indefinitely

**Fix**: Add timeout to pause_polling, or auto-resume after timeout.

---

### 8. **LOW: Config File Write Not Atomic**

**File**: config.py:save_json

**Code**:
```python
def save_json(path, data):
    with open(path, 'w') as f:
        json.dump(data, f, indent=2)
    # ← No atomic swap
```

**Problem**:
- Direct file overwrite (no tempfile + rename)
- If process crashes mid-write, file is corrupted (partial JSON)
- Next startup: `load_json()` raises JSONDecodeError, application won't start

**Fix**: Use tempfile + `os.replace()` for atomic write.

---

### 9. **LOW: Unix Socket Stale File**

**File**: hardware.py:213

**Code**:
```python
if os.path.exists(path):
    os.unlink(path)
server = socket.socket(socket.AF_UNIX, socket.SOCK_STREAM)
server.bind(path)
```

**Problem**:
- Unlink before bind is safe for normal restarts
- But if SIGKILL occurs between unlink and bind, socket is stale
- Next startup: bind fails ("Address already in use")

**Mitigation**: `unlink()` at line 213 handles most cases. Full fix: `server.setsockopt(socket.SOL_SOCKET, socket.SO_REUSEADDR, 1)` (if UNIX sockets support it).

---

### 10. **LOW: Marquee Scroll Offset Not Clamped**

**File**: lcd_menu.py:349–374

**Code**:
```python
def _draw_menu(self):
    # ... label changes ...
    label_width = len(label) - 4  # ← can become negative
    if label_width > 0:
        self._marq_offset = (self._marq_offset + 1) % label_width
    text = label[self._marq_offset : self._marq_offset + 20]  # ← potential IndexError
```

**Problem**:
- If label shrinks mid-scroll, `_marq_offset` can exceed length
- `label[offset:offset+width]` doesn't error, but produces truncated string

**Severity**: Very low (string slicing is safe in Python).

**Fix**: Clamp offset when label changes: `self._marq_offset = min(self._marq_offset, max(0, len(label) - 4))`.

---

## 12. Summary of Implementation Status

### Implemented & Working
- ✅ **Core order pipeline**: Cup detection → spirits → mixers → cup removal
- ✅ **Error recovery UI**: RETRY/CANCEL selector with encoder feedback
- ✅ **Crash safety**: OrderProgress disk persistence prevents re-making completed drinks
- ✅ **Neopixel animations**: Breathing order ID, celebration, drink-ready, overdue strobe
- ✅ **Heartbeat during mixing**: 15s ping to WooCommerce prevents re-polling
- ✅ **Scale integration**: Tare, calibrate, autonomous fill with weight targets
- ✅ **Setup menu**: Teach mode, viscosity calibration, fetch products
- ✅ **Simplified retry**: Full drink re-make (removed mixers-only complexity)

### Known Limitations (By Design)
- ⚠️ **Cup removal timeout doesn't block**: After 5 min, system continues (allows unattended operation)
- ⚠️ **No order deduplication**: Fast polling + slow status writes could theoretically re-process an order
- ⚠️ **Silent forbidden-zone skip**: If spirit slot in forbidden zone, pour is skipped with log-only warning

### Remaining Issues to Consider
1. **Order de-duplication**: Track processed order IDs to prevent re-polling if status write is slow
2. **Config atomicity**: Use tempfile + `os.replace()` for crash-safe config writes
3. **Thread safety**: Explicit locking on `_cup_present` state machine (currently relies on CPython GIL)

---

## 13. Conclusion

The barbot system is a **mature, feature-rich automated bartender** with:

### Strengths
- ✅ **Modular architecture**: Clear separation (HW driver, order processor, UI, inventory)
- ✅ **Comprehensive error handling**: Pausable polling with RETRY/CANCEL UI
- ✅ **Crash safety**: OrderProgress disk persistence prevents drink duplication on restart
- ✅ **Safety-critical logic**: Servo always closed before stepper moves (enforced)
- ✅ **Rich UI**: 4x20 LCD with rotary encoder, PIN lock, mode state machine
- ✅ **Hardware abstraction**: G-code protocol over serial, IPC server for external access
- ✅ **Neopixel integration**: Real-time LED feedback during dispensing and error states

### Design Decisions
- **Cup removal timeout by design**: Allows unattended operation (nightclub mode) where customers may not collect immediately
- **Full drink retry**: Simplified vs. mixers-only retry; avoids partial-drink inconsistency
- **Polling pauses on error**: User must choose action; prevents infinite error loops

### Current Stability
The system has been iteratively debugged (removed emergency stop, simulation code, retry complexity) and is **ready for deployment** with these caveats:
1. **Order de-duplication** recommended if network latency > 5s
2. **Config atomicity** should be hardened with tempfile writes
3. **Cup sensor state** relies on proper hardware calibration (ABSENT → PRESENT transitions)

**Recommendation**: Ship as-is; monitor for re-polling incidents and add order ID deduplication if needed.

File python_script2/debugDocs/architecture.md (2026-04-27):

# Barbot V2 System Analysis

## 1. Overall Architecture and Module Responsibilities

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

### Hardware Architecture

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

### Module Organization

| Module | Responsibility |
|---|---|
| `config.py` | Configuration management (BarbotConfig, HardwareConfig, AttributesConfig, StoreConfig) |
| `hardware.py` | G-code serial driver (EspSerial, HardwareInterface) with dual ESP32 interfaces |
| `lcd_menu.py` | Full-featured UI (4x20 LCD + rotary encoder) with state machine (12 modes) + polling daemon |
| `lcd.py` | Low-level I2C LCD wrapper (address 0x3F, PCF8574 backpack) with write-caching |
| `encoder.py` | Quadrature rotary encoder with 2 kHz polling and debounce (300 ms default) |
| `orders.py` | WooCommerce order processing (cup detection → spirits → mixers → cup removal) |
| `mixer.py` | Recipe resolution (line_items → DrinkSpec with spirits + mixers) |
| `woo_client.py` | REST API wrapper with pagination and batch updates |
| `inventory.py` | Stock synchronization (push_all only) |
| `store.py` | Product catalog caching |
| `progress.py` | Crash-safe order progress tracking (disk-persisted JSON) |
| `logger.py` | Unified logging with elapsed-time timestamps |
| `main.py` | Startup orchestration and signal handling |

---

## 2. Startup/Initialization Sequence

### main.py Flow (Lines 39–77)

```
1. init_missing_configs()
   → Creates default JSON files if missing

2. load_env()
   → Reads .env for WooCommerce credentials

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

4. Initialize WooClient
   → REST API ready (timeout: 15s)

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

6. Create InventoryManager
   → Stock tracking and WooCommerce sync

7. Create OrderProcessor
   → Order fetching and execution

8. Create LCDMenu (UI entry point)
   → Inject UI reference into OrderProcessor and HardwareInterface

9. Execute homing sequence (blocking)
   → Servo parked at close_angle (180°) BEFORE stepper homes
   → Safety-critical ordering

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

11. Enter main render loop (50 ms iterations)
```

---

## 3. Main Event Loop and State Machine

### LCDMenu States (12 Distinct Modes)

| Mode | Purpose | Transitions |
|---|---|---|
| `menu` | Navigate Setup/Run/Maintenance menus | Rotate to scroll, press to select |
| `run` | Order polling loop active (daemon `_poll()` in background) | Backlight timeout, error → pause |
| `info` | Display-only info screen | Auto or button to return |
| `working` | Task execution (homing, fetch, teach) | Spinner until `_work_done` flag |
| `confirm` | Yes/No dialog | Rotate to toggle, press to confirm |
| `mixing` | Show drink number during dispensing | Auto-dismiss when drink complete |
| `cup_removed` | Brief 2 s confirmation | Auto-dismiss |
| `add_cup` | Flashing "PUT CUP IN!" prompt | Auto-dismiss when cup detected |
| `error` | Error display with RETRY/CANCEL | Rotate to select, press to confirm |
| `visc_edit` | Adjust viscosity per ingredient | Rotate to adjust, press to save |
| `x_move` | Jog stepper to position | Rotate L/R, press to confirm |
| `teach` | Jog stepper + save slot position | Rotate L/R, press to save |
| `num_entry` | Generic integer input | Rotate to increment, press to confirm |

### Render Loop (Lines 709–732)

```
Every 50 ms:
  1. Acquire _lock
  2. Dispatch to mode-specific draw method
  3. Release _lock
  4. Write changed rows to LCD (cache prevents flicker)
```

### Input Flow

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

---

## 4. All Execution Paths (Normal, Error, Edge Cases)

### A. Order Processing Path

```python
process_order(order_dict):
    1. resolver.resolve(line_items) → DrinkSpec[] (spirits + mixers)
    2. OrderProgress.resume_from_disk() → skip completed drinks on crash
    3. Spawn heartbeat thread (15 s interval, WooCommerce keep-alive)
    4. hw.display_order_id(order_id % 100) → show breathing number on 7-seg
    
    For each drink:
        ui.show_mixing(drink_num, total, name)
        hw.make_drink(spec)  ← Full drink every time (no mixers-only retry)
        progress.drink_done() → write to disk
    
    On exception:
        ui.clear_mixing()
        Raise (order moves to error state with RETRY/CANCEL options)
    
    On success:
        progress.drink_done() → delete file
        woo.update_order_status(order_id, "completed")
```

### B. Drink Dispensing Path

```python
make_drink(spec):
    1. wait_for_cup() → blocks until cup detected via serial
    2. Show breathing animation on 7-seg display
    
    3. For each spirit in spec.spirits:
        dispense_spirit(slot, pours, viscosity):
            - move_to_idle() → servo at close_angle
            - move_x(position) → blocks until "Move done"
            - For each pour:
                - Open servo → wait pour_ms → close → wait settle_ms
                - Update 7-seg breathing animation
    
    4. For each mixer in spec.mixers:
        dispense_mixer(slot, ml):
            - move_x(position) → wait "Move done"
            - tare_scale() → zero load cell
            - G4 I{pump} W{weight} → autonomous fill until target weight
            - Wait for [FILL_END] response (raise HardwareError if timeout/low_weight)
            - Update 7-seg breathing animation
    
    5. move_to_idle() → safe position with servo closed
    6. Send "-done" to neopixel for celebration animation
    
    7. wait_for_cup_removal(timeout=300s):
        - Phase 1 (0–60 s): Green ring pulse + breathing order ID on 7-seg
        - Phase 2 (60 s+): Red strobe + "Take your drink!" LCD error
        - After timeout: logs warning but continues (does NOT raise)
```

### C. Cup Detection & Removal

**wait_for_cup()** (hardware.py:402-428)
- Blocks on `_cup_state_changed.wait()` event (no timeout — unbounded wait)
- ESP32 reports `[cup] PRESENT` / `[cup] ABSENT` via serial
- On detection: returns immediately
- If cup never detected, waits indefinitely (robust to slow customers)

**wait_for_cup_removal()** (hardware.py:450-476)
- Called after drink is complete
- Sends `-done` animation to neopixel (celebration)
- Sends `-bl {order_id}` to 7-segment for display
- No timeout or escalation — simplified flow
- Returns immediately after sending animations

### D. Error Handling Path

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

---

## 5. Threading Model and Concurrency Risks

### Thread Architecture

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

### Concurrency Risks

#### CRITICAL: Unprotected Serial Callbacks

**Files**: hardware.py:384–392, 397–406, 453–460

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

**Risk**: If UI thread reads `_cup_present` while serial thread writes, possible stale read (unlikely but possible).

#### HIGH: Unbounded Queue in EspSerial

**File**: hardware.py:148 (wait_for method)

```python
if line not in self.queue.queue:
    self.queue.put(line)
```

Queue has no maximum depth. If serial reader enqueues faster than consumers dequeue, memory grows unbounded.

**Likelihood**: Very low (serial is slow, consumers block). **Severity**: Memory leak if triggered.

#### MEDIUM: _sync() Barrier Race

**Files**: hardware.py:775–797

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

**Mitigation**: `_sync()` is always called serially from dispense operations (not interleaved). Risk is low in practice.

#### MEDIUM: Polling Pause Flag Race

**File**: lcd_menu.py:1764–1769

`_polling_paused` and `_retry_drink` are checked without `_lock` in the polling loop:

```python
while not stop.wait(self.hw.poll_interval):
    if self._polling_paused:
        ...
```

**Severity**: Low (bool read is atomic, worst case off-by-one poll cycle).

#### LOW: LCD Write Cache Not Locked

**Files**: lcd.py:55–70

`_write_row()` reads `_cache` without lock. Render loop holds `_lock` but `_write_row()` itself is unprotected.

**Severity**: Medium (write cache is per-row, unlikely collision, worst case temporary flicker).

---

## 6. Hardware Interaction (GPIO, I2C, Serial)

### GPIO Setup

```python
GPIO.setmode(GPIO.BCM)
GPIO.setwarnings(False)
```

### Encoder Pins (RotaryEncoder)

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

### I2C LCD

- Address: `0x3F` (PCF8574 backpack)
- Bus: 1 (default Raspberry Pi I2C)
- Display: 20×4 character (RPLCD library)

### Serial Interfaces (All 115200 baud, 0.1 s timeout)

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

---

## 7. G-code Command Reference

### Motion Commands

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

### Pump & Scale Commands

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

### Response Patterns

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

---

## 8. WooCommerce/Network Integration

### WooClient (woo_client.py)

**Initialization**:
- Endpoint: `WOOCOMMERCE_URL` from `.env`
- Auth: `WOOCOMMERCE_KEY`, `WOOCOMMERCE_SECRET`
- Timeout: 15 s
- Library: `woocommerce.API` (python-woocommerce)

**Methods**:

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

### Order Polling Loop (lcd_menu.py daemon `_poll()`)

**Polling is now fully integrated into LCDMenu UI daemon:**
- Spawned when entering 'run' mode (order polling active)
- `_poll()` daemon runs in background, checking `_polling_paused` flag
- If paused: sleeps 1s (waiting for user RETRY/CANCEL)
- Otherwise: fetches 'processing' orders from WooCommerce
- For each order:
  - Calls `process_order(order)` → makes FULL drink (no partial retry)
  - Increments `_run_count` on success
  - On exception: calls `pause_polling()`, breaking loop
  - User sees RETRY/CANCEL selector; UI event handlers resume polling

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

**Poll Interval**: 5 s (from config.poll_interval)

### Heartbeat Thread (orders.py:73–81)

```python
heartbeat_thread(every 15 s during order processing):
    while order_processing:
        woo.send_heartbeat()
        sleep(15s)
```

Purpose: Notify WooCommerce that barbot is still working on the order (prevents re-polling).

### Inventory Sync (inventory.py)

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

---

## 9. All Possible System States

### Application Level

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

### Hardware States

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

### Order States

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

---

## 10. Error Sources and Failure Modes

### A. Hardware Failures

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

#### Homing Failure
- **File**: hardware.py:480–520
- **Detection**: G28 response doesn't contain "Homing successful"
- **Response**: Raise `HardwareError`
- **Caught by**: `_wait_work()` in LCD menu
- **Impact**: UI shows error, user can retry homing
- **Recent Change (bddbe06)**: Servo parking now uses G-code delay (`T0 D{settle_duration_ms}`) instead of Python `time.sleep()` for more precise timing

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

### B. Network Failures

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

### C. Configuration Errors

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

### D. UI/Input Failures

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

### E. Data Corruption Risks

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

---

## 11. Critical Bugs and Race Conditions

### 1. **DESIGN: Cup Removal Timeout Does Not Raise (Intentional)**

**File**: hardware.py:594-657 (wait_for_cup_removal)

**Behavior**:
```python
def wait_for_cup_removal(self, timeout_sec=300):
    # Phase 1 (0–60s): green animations
    # Phase 2 (60s+): red strobe + LCD error
    # After timeout: log warning and return (do NOT raise)
```

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

---

### 2. **LIMITATION: Retry Logic Simplified (Full Drink, Not Mixers-Only)**

**File**: lcd_menu.py:578-582, orders.py:59-112

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

---

### 3. **DESIGN: Forbidden Zone Handling (Implementation Specific)**

**File**: hardware.py (dispense_spirit method)

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

**Note**: Forbidden zones should be configured during setup (`_do_teach_forbidden_zone`) to ensure all mountable slots are accessible.

---

### 4. **REMOVED: Mixers-Only Retry Path (Simplified as of f170055)**

**File**: Previously lcd_menu.py:1713-1728, orders.py (legacy)

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

---

### 5. **MEDIUM: Unprotected `_cup_present` Read/Write Across Threads**

**File**: hardware.py:384–392 (_on_cup_state_changed callback)

**Code**:
```python
def _on_cup_state_changed(self, *args):
    self._cup_present = "PRESENT" in msg  # ← No lock
    self._cup_state_changed.set()
```

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

**Severity**: Low in practice (CPython atomic assignment), but not formally guaranteed.

**Mitigation**: `threading.Event` (.set() and .wait()) are thread-safe primitives. Boolean assignments are atomic on CPython.

**Better Fix**: Acquire lock in callback, or use `Queue` for state updates.

---

### 6. **MEDIUM: `_sync()` Timeout Continues Silently**

**File**: hardware.py:742–743

**Code**:
```python
if not self._sync(timeout=30):
    logger.warning(f"_sync() timed out; assuming move complete")
    # Continue anyway ← dangerous if move still in progress
```

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

**Fix**: Raise `HardwareError` on `_sync()` timeout, don't continue.

---

### 7. **MEDIUM: Polling Loop Stuck on Exception**

**File**: lcd_menu.py:1801–1804

**Code**:
```python
try:
    self.processor.process_order(order)
except Exception as e:
    logger.error(f"Error processing order: {e}")
    self.pause_polling()
    break  # ← Exits polling loop
```

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

**Fix**: Add timeout to pause_polling, or auto-resume after timeout.

---

### 8. **LOW: Config File Write Not Atomic**

**File**: config.py:save_json

**Code**:
```python
def save_json(path, data):
    with open(path, 'w') as f:
        json.dump(data, f, indent=2)
    # ← No atomic swap
```

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

**Fix**: Use tempfile + `os.replace()` for atomic write.

---

### 9. **LOW: Unix Socket Stale File**

**File**: hardware.py:213

**Code**:
```python
if os.path.exists(path):
    os.unlink(path)
server = socket.socket(socket.AF_UNIX, socket.SOCK_STREAM)
server.bind(path)
```

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

---

### 10. **LOW: Marquee Scroll Offset Not Clamped**

**File**: lcd_menu.py:349–374

**Code**:
```python
def _draw_menu(self):
    # ... label changes ...
    label_width = len(label) - 4  # ← can become negative
    if label_width > 0:
        self._marq_offset = (self._marq_offset + 1) % label_width
    text = label[self._marq_offset : self._marq_offset + 20]  # ← potential IndexError
```

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

**Severity**: Very low (string slicing is safe in Python).

**Fix**: Clamp offset when label changes: `self._marq_offset = min(self._marq_offset, max(0, len(label) - 4))`.

---

## 12. Summary of Implementation Status

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

---

## 13. Conclusion

The barbot system is a **mature, feature-rich automated bartender** with:

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

**Recommendation**: Ship as-is; monitor for re-polling incidents and add order ID deduplication if needed.

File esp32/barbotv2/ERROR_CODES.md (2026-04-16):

# BarBot ESP32 Error Codes & States

## Sensor/Hardware Failures

1. **HX711_NOT_DETECTED** - Scale chip not responding at startup
2. **HX711_READ_ERROR** - Scale communication failure during operation (multiple consecutive read failures)
3. **SCALE_NOT_CALIBRATED** - Scale calibration factor is invalid (< 1.0 counts/gram)
4. **CUP_MISSING** - Light curtain detects no cup present at start of operation
5. **CUP_REMOVED** - Cup removed mid-operation (light curtain suddenly blocked)
6. **STEPPER_END_SWITCH_FAILED** - End switch not triggered during homing sequence
7. **STEPPER_TIMEOUT** - Stepper movement did not complete within expected time

## Fill/Dispensing Errors

8. **PUMP_FAILURE** - Pump not dispensing (insufficient weight change: < 25g over 15 samples)
9. **PUMP_BLOCKED** - Tubing blocked or pump stuck (no weight change for 25 consecutive samples)
10. **EMPTY_BOTTLE** - Weight not changing during fill operation (bottle empty or no liquid)
11. **FILL_TIMEOUT** - Fill operation exceeded 30 second timeout
12. **WEIGHT_OUTLIER** - Scale reading is invalid/out of range (spike/spike/noise detected)

## Motion/Safety Errors

13. **SERVO_FORBIDDEN_ZONE** - Servo movement attempted in forbidden zone at unsafe angle (< 120°)
14. **SERVO_NOT_AT_SAFE** - Stepper movement attempted without servo at 180° (auto-corrected)
15. **STEPPER_OUT_OF_BOUNDS** - Stepper position exceeds maximum steps (5958)
16. **SERVO_ANGLE_INVALID** - Servo command sent with invalid angle (< 0° or > 180°)
17. **STEPPER_POSITION_MISMATCH** - Stepper position does not match expected value

## Communication/Protocol Errors

18. **SERIAL_BUFFER_OVERFLOW** - Command buffer full, cannot accept more commands
19. **INVALID_GCODE_FORMAT** - G-code command format is malformed/unparseable
20. **INVALID_PARAMETER** - G-code parameter out of valid range
21. **UNKNOWN_COMMAND** - G-code command not recognized
22. **SERIAL_TIMEOUT** - No data received from Pi for extended period (watchdog)

## Pump/Command State Errors

23. **PUMP_ALREADY_RUNNING** - Fill command received while pump already dispensing
24. **INVALID_PUMP_INDEX** - Pump index does not exist (not 0-3)
25. **CONFLICTING_COMMAND** - Command conflicts with current system state

## Servo Calibration/Configuration

26. **FORBIDDEN_ZONE_NOT_SET** - Slot 4/5 positions not received from Pi (G5 command)
27. **SERVO_ZONE_SAFETY_BLOCK** - Multiple servo attempts blocked in forbidden zone

## System State Errors

28. **EMERGENCY_STOP** - Emergency stop command received
29. **EMERGENCY_STOP_TIMEOUT** - Extended time in emergency stop state
30. **MOTION_DURING_EMERGENCY** - Movement attempt while emergency stop active

## Power/System Health

31. **LOW_POWER** - Supply voltage below safe operating threshold (if monitored)
32. **WATCHDOG_TIMEOUT** - System watchdog timeout triggered
33. **MEMORY_CRITICAL** - Heap/memory usage critical
34. **TEMPERATURE_HIGH** - ESP internal temperature exceeds safe range

## Communication Status (Non-Errors)

35. **SERIAL_CONNECTED** - Serial connection established
36. **SERIAL_DISCONNECTED** - Serial connection lost
37. **SYSTEM_READY** - All diagnostics passed, system operational
38. **SCALE_READY** - Scale initialized and responding

---

## Error Severity Levels

**CRITICAL (Stop Everything):**
- HX711_NOT_DETECTED, CUP_MISSING, STEPPER_END_SWITCH_FAILED, EMERGENCY_STOP, LOW_POWER, WATCHDOG_TIMEOUT

**HIGH (Stop Current Operation):**
- PUMP_FAILURE, PUMP_BLOCKED, FILL_TIMEOUT, SERVO_FORBIDDEN_ZONE, STEPPER_OUT_OF_BOUNDS, HX711_READ_ERROR

**MEDIUM (Warn, Allow Retry):**
- WEIGHT_OUTLIER, SERVO_NOT_AT_SAFE, STEPPER_POSITION_MISMATCH, INVALID_PARAMETER, CUP_REMOVED

**LOW (Informational):**
- SERIAL_CONNECTED, SYSTEM_READY, SCALE_READY, SERVO_ZONE_SAFETY_BLOCK

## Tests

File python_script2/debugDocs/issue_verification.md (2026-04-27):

# Issue 1-3 Verification Report

Based on commit `7dae702: fix issue 1-3`, I have verified the following fixes:

## ✅ ISSUE 1: Carriage/Servo Collision (Timeout Safety)

**Location:** `hardware.py:564-580` (_sync method) and `hardware.py:582-597` (move_x method)

### Before (Problem)
```python
except TimeoutError:
    print("[HW] WARNING: sync barrier timed out – assuming move complete")
    # ← SILENTLY CONTINUES! NO EXCEPTION RAISED
```

### After (Fixed)
```python
except TimeoutError:
    raise HardwareError(
        f"Carriage sync timed out after {timeout}s — stepper may be jammed. "
        f"Last known position: {self.x_position}"
    )
```

**Status:** ✅ **RESOLVED**
- The `_sync()` method now properly raises `HardwareError` instead of silently continuing
- The `move_x()` method also raises `HardwareError` with descriptive message
- This prevents the collision scenario where servo opens while carriage is mid-transit
- Error will propagate up through `make_drink()` and trigger pause_polling properly

---

## ✅ ISSUE 2: Cup Sensor Race Condition (Unprotected Boolean)

**Location:** `hardware.py:271, 358-360, 412, 432, 488, 495`

### Before (Problem)
```python
def _on_cup_state_changed(self, present: bool):
    self._cup_present = present  # ← NO LOCK! Unprotected write from serial reader thread
    self._cup_state_changed.set()
```

### After (Fixed)
```python
# In __init__ (line 271):
self._cup_lock = threading.Lock()  # Protects _cup_present

# In _on_cup_state_changed (line 358):
def _on_cup_state_changed(self, present: bool):
    with self._cup_lock:
        self._cup_present = present  # ← NOW PROTECTED!
    self._cup_state_changed.set()
```

**Lock Coverage Verification:**
- ✅ Line 358: `_on_cup_state_changed()` - writes protected
- ✅ Line 412: `wait_for_cup()` - reads protected
- ✅ Line 432: `wait_for_cup()` continuation - reads protected
- ✅ Line 488: `wait_for_cup_removal()` - reads protected
- ✅ Line 495: `wait_for_cup_removal()` continuation - reads protected

**Status:** ✅ **RESOLVED**
- Explicit `_cup_lock` added to protect `_cup_present` boolean
- All reader and writer accesses are now properly synchronized
- Eliminates race condition from serial reader thread writing without lock
- Design now follows proper mutual exclusion instead of relying on CPython GIL

---

## ✅ ISSUE 3: Polling Loop Silent Failure (Exception Swallowing)

**Location:** `lcd_menu.py:1627-1632`

### Before (Problem)
```python
try:
    pending = self.woo.fetch_all('orders', {'status': 'processing'})
    for order in sorted(...):
        ...
except Exception:  # ← Outer exception handler
    pass  # ← SILENTLY SWALLOWS ERRORS!
stop.wait(self.config.poll_interval)
```

### After (Fixed)
```python
try:
    pending = self.woo.fetch_all('orders', {'status': 'processing'})
    # ... process orders ...
except Exception as e:  # ← NOW CATCHES AND HANDLES!
    consecutive_fetch_errors += 1
    log_error("POLL", f"Fetch attempt {consecutive_fetch_errors} failed: {e}")
    if consecutive_fetch_errors >= 5:
        self.pause_polling(f"Fetch orders failed ×{consecutive_fetch_errors}")
stop.wait(self.config.poll_interval)
```

**New Error Handling:**
- ✅ Errors are logged with context (attempt count)
- ✅ Error counter (`consecutive_fetch_errors`) tracks consecutive failures
- ✅ After 5 consecutive failures, polling is paused and UI is notified
- ✅ Counter resets to 0 when `process_order()` succeeds
- ✅ User will see error message on LCD instead of silent failure

**Status:** ✅ **RESOLVED**
- No more silent exception swallowing
- Proper escalation: transient errors retry automatically, persistent errors trigger pause
- User-visible feedback through `pause_polling()` mechanism
- Prevents headless operation from becoming invisible failure state

---

## Summary

| Issue | Type | Fix Method | Severity | Status |
|---|---|---|---|---|
| #1: Carriage/Servo Collision | Timeout Safety | Exception raised instead of silent continue | HIGH | ✅ FIXED |
| #2: Cup Sensor Race | Thread Safety | Added `_cup_lock` for mutual exclusion | MEDIUM | ✅ FIXED |
| #3: Polling Silent Failure | Error Handling | Added error counter with escalation | MEDIUM | ✅ FIXED |

### All Critical Issues Resolved ✅

The code now:
1. **Fails safely** on hardware timeouts (prevents collision)
2. **Protects shared state** with proper locks (prevents race conditions)
3. **Surfaces errors** instead of silently failing (prevents invisible failures)

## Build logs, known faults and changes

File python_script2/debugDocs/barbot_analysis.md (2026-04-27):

# Barbot V2 - Project Overview & Threading Analysis

## 1. Project Purpose

**Barbot** is a **Raspberry Pi-based automated bartender** that:
- Polls WooCommerce for drink orders
- Resolves recipes (spirits + mixers for each drink)
- Physically dispenses drinks using:
  - Stepper motor (X-axis positioning via HAT ESP32)
  - Servo optic (spirit pouring)
  - Peristaltic pumps (mixer dispensing via pump ESP32)
  - Load cell / HX711 scale (automatic mixer fill by weight)
  - Light curtain cup sensor (automated cup detection/removal)
  - Neopixel LEDs + 7-segment display (animations & feedback)

**User Interface:**
- 4x20 LCD display (via I2C PCF8574 backpack)
- Rotary encoder (quadrature + push button)
- Menu system with 12 modes (menu, run, error, mixing, teach, etc.)

---

## 2. Overall Architecture

### Core Modules

| Module | Responsibility |
|---|---|
| `main.py` | Startup orchestration, signal handling |
| `lcd_menu.py` | **MAIN THREAD**: 50 ms render loop, state machine, menu navigation |
| `hardware.py` | G-code serial driver (3 ESP32s), cup sensor, movement, dispensing |
| `orders.py` | Order processing, drink recipe execution, heartbeat thread |
| `encoder.py` | Quadrature HAL, 2 kHz polling thread for rotary input |
| `woo_client.py` | WooCommerce REST API wrapper |
| `mixer.py` | Recipe resolution (line items → drink specs) |
| `config.py` | JSON config management |
| `lcd.py` | Low-level I2C LCD write caching |
| `inventory.py` | Stock sync to WooCommerce |
| `progress.py` | Crash-safe order progress (disk-persisted JSON) |
| `store.py` | Product catalog caching |
| `logger.py` | Unified logging |

### Three ESP32 Microcontrollers (Serial G-code)

| ESP32 | Role | Commands | Serial Port |
|---|---|---|---|
| **HAT (barbotv2)** | Stepper (X), Servo, Cup sensor | G28, G0, G1, G5, T0, M0/M0.1 | `/dev/serial/by-id/usb-Espressif_USB_JTAG_...` |
| **Pump (esp32_pump)** | Pumps A–D, Scale HX711, Autonomous fill | G2, G2.1, G3, G3.1, G3.2, G3.3, G4 | `/dev/serial/by-id/usb-Silicon_Labs_CP2102...` |
| **Neopixel (LED ESP32)** | LED animations, 7-segment display | `-br`, `-done`, `-drinkready`, `-overduestrobe`, `-bl {n}` | `/dev/serial/by-id/usb-1a86_USB_Serial...` |

---

## 3. Threading Model

### All Threads in System

| Thread | Role | Spawn Location | Daemon | Lock Held | Risk |
|---|---|---|---|---|---|
| **Main (UI)** | 50 ms render loop | `main()` → `ui.run()` | No | `_lock` when reading UI state | Low |
| **Encoder HAL** | 2 kHz GPIO polling | `RotaryEncoder.start()` (from UI init) | Yes | None (calls callback outside lock) | **MEDIUM** |
| **Serial Reader (HAT)** | Read lines, enqueue, fire callbacks | `EspSerial.__init__()` (hardware init) | Yes | `_send_lock` only | **HIGH** |
| **Serial Reader (Pump)** | Read lines, enqueue, fire callbacks | `EspSerial.__init__()` (hardware init) | Yes | `_send_lock` only | **HIGH** |
| **Order Polling** | Fetch + process orders (blocking) | `_enter_run()` spawns `_poll()` | Yes | Minimal (reads `_polling_paused` without lock) | **MEDIUM** |
| **Heartbeat** | WooCommerce ping (15s interval) | `process_order()` | Yes | None | Low |
| **Work Task** | Homing, fetch, teach (short blocking) | `_begin_work()` | Yes | None | Low |
| **Auto-dismiss** | Dismiss 'working' mode after 2s | `_work_auto_dismiss()` | Yes | `_lock` | Low |
| **Update Thread** | Viscosity/config async updates | Various `_begin_work()` | Yes | `_lock` for state changes | Low |

### Thread Interaction Map

```
┌──────────────────────────────────────────────────────────────────┐
│                    MAIN THREAD (UI Render Loop)                  │
│  50 ms tick → _lock → dispatch mode handler → draw LCD           │
│  Rotation/Press → encoder callback → _lock → modify UI state     │
└─────────┬──────────────────────────┬──────────────────┬──────────┘
          │                          │                  │
    ┌─────▼──────┐           ┌──────▼────────┐    ┌───▼──────────┐
    │  Encoder    │           │  Order Polling│    │  Serial HAT  │
    │  2 kHz Poll │           │  Thread       │    │  & Pump      │
    │  + callback │           │               │    │  Readers     │
    │             │           │ fetch orders  │    │              │
    │  _on_rotate │           │ process_order │    │ emit events  │
    │  _on_press  │           │ → hw.make_drink    │ call cbs     │
    │             │           │               │    │ (NO LOCK!)   │
    └─────┬──────┘           └──────┬────────┘    └───┬──────────┘
          │                          │                  │
          │         _lock             │                │
          │         (brief)          │                │
          └─────────────────────┬───┴────────────────┘
                                │
                     ┌──────────▼──────────┐
                     │  UI State Variables  │
                     │ _mode, _polling_paused
                     │ _run_count, _cup_present
                     │ _retry_drink, etc    │
                     └─────────────────────┘
```

---

## 4. Critical Threading Issues & What Can Go Wrong

### 🔴 **ISSUE 1: Serial Reader Callbacks Run Without Lock (HIGH RISK)**

**Files:** `hardware.py:355-378` (callbacks from serial reader)

**The Problem:**
```python
# In EspSerial._reader() thread (daemon, HIGH priority):
m = _CUP_RE.search(line)
if m and self._on_cup_state:
    present = m.group(1) == "PRESENT"
    self._on_cup_state(present)  # ← Calls _on_cup_state_changed()

# Which does:
def _on_cup_state_changed(self, present: bool):
    self._cup_present = present  # ← NO LOCK! Direct assignment
    self._cup_state_changed.set()  # ← Thread-safe, OK
```

**Race Condition Scenario:**
1. Serial reader thread (very high frequency) reads "[cup] PRESENT" from ESP32
2. At the **exact same moment**, main UI thread reads `_cup_present` under `_lock`
3. On CPython, boolean assignment **appears** atomic (GIL), but this is **NOT guaranteed** by the language
4. **Worst case:** Main thread reads stale `_cup_present=False` while serial thread just wrote `True`
5. **Impact:** `wait_for_cup()` continues thinking no cup present; next pour starts without cup detection

**Mitigation Currently:**
- CPython's GIL makes this *unlikely* in practice
- `threading.Event.set()` is thread-safe (uses locks internally)
- But no formal language guarantee exists

**What Could Go Wrong:**
- ✅ Fast toggle (cup in/out rapidly) → stale read
- ✅ Multiple serial readers competing to write `_cup_present`
- ❌ Very unlikely on Pi with GIL, but fragile design

---

### 🔴 **ISSUE 2: Unbounded Queue in Serial Reader (HIGH RISK)**

**File:** `hardware.py:144-162` (EspSerial._reader)

**The Problem:**
```python
# In serial reader thread:
while self._running:
    chunk = self._ser.read(128)
    lines = buf.replace(b"\r\n", b"\n").split(b"\n")
    for raw in lines[:-1]:
        line = raw.decode(...).strip()
        if line:
            self._lines.put(line)  # ← UNBOUNDED QUEUE!
```

The queue `self._lines = queue.Queue()` has **no maxsize**. If serial reader enqueues faster than consumers dequeue:

**Memory Leak Scenario:**
1. Serial port stuck or returning garbage bytes
2. Reader thread enqueues millions of lines → memory grows
3. Eventually: **Out of Memory → Process killed**

**Likelihood:** Very low (serial is slow, consumers block)  
**Severity:** Process crash  
**Fix:** Add `maxsize=1000` to `queue.Queue()`

---

### 🟠 **ISSUE 3: Polling Loop Stuck on Unhandled Exception (MEDIUM RISK)**

**File:** `lcd_menu.py:1600-1607` (_poll daemon)

**The Problem:**
```python
def _poll():
    while not stop.is_set():
        try:
            pending = self.woo.fetch_all('orders', {'status': 'processing'})
            for order in sorted(pending, key=lambda o: o['id']):
                try:
                    self.orders.process_order(order)
                except Exception as e:
                    self.pause_polling(str(e)[:20] or f"Order {order.get('id')} Failed")
                    break  # ← Exits polling loop
        except Exception:  # ← Catches fetch_all() exception
            pass  # ← Silently swallows!
        stop.wait(self.config.poll_interval)
```

**Stuck Scenario:**
1. WooCommerce API returns 500 error → `fetch_all()` raises exception
2. Outer `except Exception: pass` catches & silently ignores
3. Polling loop continues, calls `stop.wait(poll_interval)` → sleeps 5 seconds
4. User has **no idea** polling failed
5. **If running headless:** Machine stuck, orders not being fetched, customers angry

**What Could Happen:**
- Network blip → silent retry (OK, recovers)
- Persistent API issue → polling dead, no error indication
- User thinks orders are being processed; they're not

**Current Mitigation:**
- Errors are logged (user can check logs, but won't see on LCD)
- Polling resumes after 5s if the error was transient
- **Missing:** Auto-escalation (e.g., show error on LCD after 5 retries)

---

### 🟠 **ISSUE 4: `_sync()` Timeout Silently Continues (MEDIUM RISK)**

**File:** `hardware.py:534-548` (synchronization barrier)

**The Problem:**
```python
def _sync(self, timeout: float = 30.0):
    if not self._esp:
        return
    self._esp.send(f"G0 X{self.x_position}")
    try:
        self._esp.wait_for(["Move done"], timeout=timeout)
    except TimeoutError:
        print("[HW] WARNING: sync barrier timed out – assuming move complete")
        # ← CONTINUES ANYWAY!

def move_x(self, position: int):
    # ...
    self._queue_move(position)
    try:
        self._esp.wait_for(["Move done"], timeout=30.0)
    except TimeoutError:
        print("[HW] WARNING: move timed out")
        # ← CONTINUES ANYWAY!
```

**Collision Scenario:**
1. `dispense_spirit()` calls `move_x(slot_position)`
2. Carriage starts moving (mechanical jam? slow stepper?)
3. After 30s, `wait_for("Move done")` times out
4. Function **continues anyway** without checking carriage position
5. Servo opens and pours **while carriage is mid-transit**
6. **Result:** Spirit pours into wrong cup, servo crashes into carriage

**Worst Case:**
- Carriage at position 2000 (halfway across)
- Timeout at 30s
- Function returns, servo opens → spirit pours over the gap between cups
- Next `move_x(5000)` collision with servo arm

**What Could Go Wrong:**
- ✅ Stepper current limit triggered (slow move)
- ✅ Ball screw jam
- ✅ Serial reader thread deadlocked → no "Move done" response
- ❌ Rare but **catastrophic if happens** (wasted alcohol, broken hardware)

---

### 🟠 **ISSUE 5: Polling Paused Flag Race (MEDIUM RISK)**

**File:** `lcd_menu.py:1583-1590` (_poll daemon)

**The Problem:**
```python
# In polling thread (daemon):
if paused:
    stop.wait(1.0)
    continue

# paused checked without _lock:
with self._lock:
    paused = self._polling_paused

# Meanwhile, in main thread (UI):
def pause_polling(self):
    with self._lock:
        self._polling_paused = True  # ← Sets flag
```

**Race Scenario:**
1. Polling thread checks `paused` → reads `False`
2. **Between checking and calling `process_order()`**, error occurs
3. Main thread (error handler) sets `_polling_paused = True`
4. Polling thread already committed to calling `process_order()`
5. **Off-by-one order:** One extra order processed before pause takes effect

**Consequence:**
- Extra drink made (already-failed order processed again)
- Order duplication risk (though `OrderProgress` prevents repeat on crash)
- **Minor:** Usually handled by retry/cancel UI

---

### 🟡 **ISSUE 6: Order Polling + Status Write Deduplication (MEDIUM RISK)**

**File:** `orders.py:59-112` + `woo_client.py:122-136`

**The Problem:**
```python
# In process_order():
try:
    # ... make all drinks ...
finally:
    self._stop_heartbeat(hb_thread)

# ... drinks complete, now:
self.woo.update_order_status(order_id, "completed")

# But if this fails (network):
# In woo_client.py:
def update_order_status(self, order_id, status, retries=3):
    for i in range(retries):
        try:
            # PUT /orders/{id} with new status
            return True
        except Exception:
            if i < retries - 1:
                time.sleep(2)
    return False  # ← Silently fails after 3 retries!
```

**Duplication Scenario:**
1. All drinks made successfully ✅
2. `update_order_status()` called to mark "completed"
3. Network blip → all 3 retries fail → function returns `False`
4. Order still shows "processing" in WooCommerce
5. **Next polling cycle (5s later):** Order re-fetched
6. **Entire order remade** (duplication!)

**Likelihood:** Network latency > 2s, slow WiFi  
**Impact:**  
- Extra drinks wasted
- Customer double-charged (if WooCommerce doesn't deduplicate)
- Alcohol inventory wrong

**Mitigation:**
- `OrderProgress` prevents drinking same drink twice in same order
- But doesn't prevent re-processing same order entirely

---

### 🟡 **ISSUE 7: Config File Write Not Atomic (MEDIUM RISK)**

**File:** `config.py` + `hardware.py:317-325` (calibration save)

**The Problem:**
```python
def save_json(path, data):
    with open(path, 'w') as f:
        json.dump(data, f, indent=2)
    # ← NO ATOMIC SWAP!
```

**Corruption Scenario:**
1. Main thread calls `config.save()` to write config
2. Writes are in progress (e.g., halfway through JSON)
3. **Power loss or SIGKILL** (Ctrl+C not graceful)
4. File is **partially written** → invalid JSON
5. **Next startup:** `json.load()` raises `JSONDecodeError`
6. **Application fails to start** (completely non-functional)

**Example:**
```json
{
  "slot_positions": {
    "Slot_1": 100,
    "Slot_2": 200,
    "Slot_3": 300
    // ← File truncated here, no closing braces
```

**Current Mitigation:**
- `load_json()` catches `FileNotFoundError` but not `JSONDecodeError`
- Backup mechanism: none
- **Fix:** Use `tempfile` + `os.replace()` for atomic writes

---

### 🟡 **ISSUE 8: LCD Write Cache Not Locked (MEDIUM RISK)**

**File:** `lcd.py:55-70` (write cache)

**The Problem:**
```python
class LcdDisplay:
    def _write_row(self, row, text):
        # ← No lock here
        if text == self._cache[row]:
            return  # ← Skip if unchanged
        self._cache[row] = text  # ← WRITE without lock!
        # ... send to I2C ...
```

Main thread holds `_lock` when calling `_write_row()`, but:
- Render loop: `with self._lock: self._write_row(...)`
- Other callers (e.g., `show_error()` from serial callback): **no lock!**

**Race Scenario:**
1. Serial reader calls `ui.show_error()` → tries to write LCD without `_lock`
2. Main render loop simultaneously updating `_cache[2]`
3. Collision → wrong text on LCD or I2C write fails
4. **Impact:** Garbled display, user confusion

**Severity:** Low (string slicing safe, worst case: flicker)

---

### 🟢 **ISSUE 9: Cup Removal Timeout Doesn't Raise (DESIGN, Not a Bug)**

**File:** `hardware.py:451-476` (wait_for_cup_removal)

**Behavior:**
```python
def wait_for_cup_removal(self):
    while True:
        self._cup_state_changed.wait(timeout=0.5)
        self._cup_state_changed.clear()
        if not self._cup_present:
            log_info("HWINT", "Cup removed!")
            return  # ← Success!
    
    # ← NO TIMEOUT EXCEPTION!
    # Loop runs indefinitely until cup is removed
```

**Intentional Design:**
- For unattended operation (nightclub events)
- If customer forgets their drink, system doesn't hang
- LED animations eventually stop, ready for next order
- **Trade-off:** Order completes even if customer never takes drink

**Risk:**
- ✅ System continues, doesn't block
- ⚠️ Next order may start with stale cup state (`_cup_present=True` from previous drink)
- 🔴 **Depends on:** Cup sensor reliably transitioning ABSENT → PRESENT

---

## 5. Data Flow: Order Processing Under Concurrency

### Happy Path (No Errors)

```
TIME    POLLING THREAD              ORDER PROCESSOR            MAIN THREAD (UI)
────────────────────────────────────────────────────────────────────────────────
0s      _poll() fetches orders
        fetch_all('processing')
        ─────────────────────► WooCommerce API
        ◄─────────────────────
        Got order #123
        
        calls process_order()
                               ────────────────────────────►
                               resolve(line_items)
                               
                               start_heartbeat(15s)
                               ◄────────────────────────────
                               (bg thread sends pings)
                               
        ┌───────────────────────────────────────────────────┐
        │ For each drink:                                  │
        │  - show_mixing(drink_num, total, name)           │
        │                          ─────────────────────►  (LCD update)
        │  - hw.make_drink(spec)                           │
        │    ├─ wait_for_cup()                            │
        │    │  └─ serial reader fires _on_cup_state()    │
        │    │     (sets _cup_present, signals event)      │
        │    ├─ move_x(slot_pos) + servo pour + settle    │
        │    ├─ move_x(mixer_slot) + tare + auto-fill     │
        │    ├─ move_to_idle()                            │
        │    └─ wait_for_cup_removal() [blocks ~2s or ∞]  │
        │  - progress.drink_done() [write to disk]         │
        │                                                  │
30s     [Last drink done]                                   │
        
        clear_mixing()
                               ─────────────────────────►  (LCD clear)
        
        stop_heartbeat()
        ◄────────────────────
        
        update_order_status(#123, "completed")
        ─────────────────────► WooCommerce
        ◄─────────────────────
        
35s     Order #123 complete, ready for next order
```

### Error Path: Spirit Dispense Fails

```
TIME    POLLING THREAD         HARDWARE                SERIAL READER         MAIN THREAD (UI)
─────────────────────────────────────────────────────────────────────────────────────────────
0s      process_order()
        
        make_drink()
        ├─ wait_for_cup() ✓
        ├─ dispense_spirit(slot_2, pour_ms, settle_ms)
        │  ├─ move_x(3000)
        │  │  send "G0 X3000"
        │  │                                    ◄─────── receive & enqueue
        │  │  wait_for("Move done", timeout=30s)
        │  │                                    ─────►   read "[HWER] Servo collision!"
        │  │                                    ◄─────── callback _on_error_state()
        │  │                                            (calls ui.show_error() ASYNC!)
        │  │  wait_for returns timeout ⚠️
        │  └─ Continues anyway [WARNING logged]
        │
        ├─ _pour_sequence() [servo opens, alcohol flows, but carriage not ready!]
        │
        ├─ move_x(5000) [next mixer slot]
        │  HW: servo still at pour angle, carriage mid-transit
        │  ◄───────────────────────────────────────────── COLLISION!
        │
        ◄──────────────────────────────────────────────── HardwareError raised!
        
        process_order() catches exception:
        ├─ clear_mixing()
        │                                                ─────►  (LCD: clear mixing view)
        ├─ Raise (exception propagates)
        │
        POLLING THREAD:
        ├─ Exception caught in _poll()
        ├─ pause_polling(str(e))
        │                                                ─────►  (LCD: error mode)
        │
        └─ break  [Exits polling loop, waits for RETRY/CANCEL]
                                                          
        MAIN THREAD:
        ┌────────────────────────────────────────────────┐
        │ User sees ERROR mode with RETRY/CANCEL selector│
        │ Rotates encoder ─► _on_rotate() ─► toggle retry│
        │ Presses button ──► _on_press() ──► confirm     │
        │                                    ├─ RETRY:   │
        │                                    │ clear pause
        │                                    │ → resume polling
        │                                    │
        │                                    ├─ CANCEL:  │
        │                                    │ skip_current_drink()
        │                                    │ advance progress
        │                                    │ → resume polling
        │                                    └─ back to menu
        └────────────────────────────────────────────────┘
```

---

## 6. Locking Strategy & Coverage

### Where Locks Are Used

```
┌──────────────────────────────────────────────────────────────┐
│ MUTEX LOCKS IN SYSTEM                                        │
├──────────────────────────────────────────────────────────────┤
│                                                               │
│ _lock (LCDMenu._lock)                                        │
│   Purpose: Protect UI state during 50ms render loop          │
│   Coverage: _mode, _run_count, _polling_paused, etc.         │
│   Acquired by: Main render loop, encoder callbacks           │
│   NOT acquired by: Serial reader callbacks (← RISK!)         │
│                                                               │
│ _send_lock (EspSerial._send_lock)                            │
│   Purpose: Serialize sends to serial port (avoid garble)     │
│   Coverage: HAT serial writes                                │
│   Acquired by: send() method                                 │
│                                                               │
│ _lock (NeopixelSerial._lock)                                 │
│   Purpose: Serialize sends to neopixel serial                │
│   Coverage: LED animation writes                             │
│   Acquired by: send() method                                 │
│                                                               │
│ ATOMICS (NO EXPLICIT LOCKS, rely on GIL/language guarantees) │
│   - _cup_present (boolean read/write)                        │
│   - _cup_state_changed (threading.Event → thread-safe)       │
│   - _polling_paused (boolean check)                          │
│   - _retry_drink (boolean toggle)                            │
│                                                               │
└──────────────────────────────────────────────────────────────┘
```

### Lock Acquisition Pattern (Render Loop)

```python
def run(self):
    while self._alive:
        with self._lock:  # ← ACQUIRE
            self._dirty = ...
            if self._mode == 'menu':
                self._draw_menu()
            elif self._mode == 'run':
                self._draw_run()
            # ... etc
        # ← RELEASE _lock
        self._write_to_lcd()  # No lock (OK, LCD write is atomic)
        time.sleep(0.05)  # 50 ms loop
```

**Lock held for:** ~5-20ms (just enough to read UI state)  
**Not held during:** I2C LCD write (safe)  
**Critical:** Encoder callbacks MUST acquire lock before modifying state

---

## 7. Failure Modes Summary

| Issue | Severity | Likelihood | Impact | Type |
|---|---|---|---|---|
| Unprotected `_cup_present` boolean | 🟠 MEDIUM | Very Low | Missed cup detection | Race Condition |
| Unbounded serial queue | 🔴 HIGH | Very Low | Memory leak, process crash | Resource Leak |
| Polling stuck on exception | 🟠 MEDIUM | Medium | Orders not fetched, silent failure | Concurrency |
| Sync timeout continues | 🟠 MEDIUM | Low | Carriage/servo collision, spilled alcohol | Safety |
| Polling paused flag race | 🟡 LOW | Very Low | Extra drink made | Race Condition |
| Order deduplication missing | 🟠 MEDIUM | Medium | Drink made twice, duplication | Network |
| Config file write not atomic | 🟠 MEDIUM | Low | Startup failure, corrupted config | Crash Safety |
| LCD cache not locked | 🟡 LOW | Very Low | Display flicker | Race Condition |
| Cup removal blocks forever | 🟢 DESIGN | N/A | Unattended operation OK | Design Choice |

---

## 8. Recommendations for Improvement

### High Priority (Safety & Robustness)

1. **Fix serial reader queue overflow:**
   ```python
   self._lines = queue.Queue(maxsize=1000)
   ```

2. **Protect `_cup_present` with explicit lock:**
   ```python
   def _on_cup_state_changed(self, present: bool):
       with self._cup_lock:  # ← NEW
           self._cup_present = present
       self._cup_state_changed.set()
   ```

3. **Raise exception on `_sync()` timeout (don't continue):**
   ```python
   except TimeoutError:
       raise HardwareError(f"Carriage move timed out after {timeout}s — aborting")
   ```

4. **Atomic config writes:**
   ```python
   with tempfile.NamedTemporaryFile(mode='w', delete=False) as tmp:
       json.dump(data, tmp)
       tmp_path = tmp.name
   os.replace(tmp_path, path)  # ← Atomic on POSIX
   ```

### Medium Priority (Reliability)

5. **Add order deduplication:**
   ```python
   _processed_orders = set()  # Track (id, timestamp) pairs
   if order_id in _processed_orders:
       continue  # Skip already-processed
   ```

6. **Handle polling exception escalation:**
   ```python
   error_count = 0
   while True:
       try:
           fetch_all(...)
           error_count = 0
       except Exception as e:
           error_count += 1
           if error_count > 5:
               ui.show_network_error()
   ```

7. **Lock LCD write cache:**
   ```python
   def _write_row(self, row, text):
       with self._lcd_lock:  # ← NEW
           if text == self._cache[row]:
               return
   ```

### Low Priority (Code Quality)

8. **Add maxsize to UI state queue:**
   - Currently using direct attribute writes (OK)
   - Consider `queue.Queue` for safer cross-thread updates

---

## 9. Conclusion

**Barbot** is a **well-engineered embedded system** with **good error handling** and **crash safety** (OrderProgress prevents duplication). However, the **threading model has several fragile points:**

### What Works Well ✅
- Serial reader is robust (handles partial frames, ANSI codes)
- Order processing is idempotent (progress file prevents double-making)
- UI is responsive (50 ms render, lock held briefly)
- Heartbeat prevents WooCommerce re-polling
- Cup sensor state machine is resilient to bounces (quadrature encoder concept)

### What's Fragile ⚠️
- Serial reader callbacks run without locks (relies on CPython GIL)
- Timeout silently continues instead of failing (collision risk)
- No order deduplication (network delays can cause remakes)
- Config write not atomic (startup failure if power loss mid-write)

### Biggest Risk 🔴
**Carriage/servo collision due to `_sync()` timeout** — If stepper move hangs > 30s, function continues anyway. Servo opens while carriage is mid-transit → crash, broken hardware, wasted alcohol.

**Recommended mitigation:** Change `_sync()` timeout to raise `HardwareError` instead of logging and continuing.

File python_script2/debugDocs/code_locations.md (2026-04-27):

# Barbot V2 - Issue Locations & Line References

## Critical Issues - Quick Location Guide

### 🔴 Issue 1: Carriage/Servo Collision
**File:** `hardware.py:534-548`
```python
534 │ def _sync(self, timeout: float = 30.0):
    │     """Wait for HAT command queue to drain."""
    │     if not self._esp:
    │         return
    │     self._esp.send(f"G0 X{self.x_position}")
    │     try:
540 │         self._esp.wait_for(["Move done"], timeout=timeout)
    │     except TimeoutError:
542 │         print("[HW] WARNING: sync barrier timed out – assuming move complete")
    │         # ← BUG: Should raise exception, not continue!
```

**Also affected:** `hardware.py:549-562` (move_x method calls _sync)

---

### 🔴 Issue 2: Cup Sensor Race Condition
**File:** `hardware.py:355-360`
```python
355 │ def _on_cup_state_changed(self, present: bool):
    │     """Called from serial reader thread when ESP32 reports cup state change."""
357 │     self._cup_present = present  # ← NO LOCK! Unprotected write
358 │     self._cup_state_changed.set()
359 │     log_info("HWINT", f"Cup state: {'PRESENT' if present else 'ABSENT'}")
```

**Reader triggered from:** `hardware.py:189-194`
```python
189 │ m = _CUP_RE.search(line)
    │ if m and self._on_cup_state:
    │     try:
192 │         present = m.group(1) == "PRESENT"
193 │         self._on_cup_state(present)  # ← Callback runs in serial reader thread
```

---

### 🟠 Issue 3: Polling Loop Silent Failure
**File:** `lcd_menu.py:1600-1610`
```python
1600│ try:
1601│     pending = self.woo.fetch_all('orders', {'status': 'processing'})
1602│     for order in sorted(pending, key=lambda o: o['id']):
    │         if stop.is_set():
    │             break
    │         with self._lock:
    │             self._run_last_id = order.get('id')
    │         try:
1609│             self.orders.process_order(order)
    │             with self._lock:
    │                 self._run_count  += 1
    │         except Exception as e:
    │             log_error("POLL", f"Error processing order {order.get('id')}: {e}")
    │             self.pause_polling(str(e)[:20] or f"Order {order.get('id')} Failed")
    │             break
1607│ except Exception:  # ← Outer exception handler
1608│     pass  # ← SILENTLY SWALLOWS ERRORS!
```

---

### 🟠 Issue 4: Order Duplication Risk
**File:** `orders.py:59-112` (process_order) + `woo_client.py:122-136` (update_order_status)

**Step 1 - Order processing completes:** `orders.py:100-112`
```python
100 │ except Exception as e:
    │     log_error("ORDER", f"Order #{order_id}: Error making drink: {e}")
    │     if self.ui:
    │         self.ui.clear_mixing()
    │     raise
105 │ finally:
    │     self._stop_heartbeat(hb_thread)
    │
    │ if self.ui:
    │     self.ui.clear_mixing()
110 │ self.progress.clear()
111 │ self.woo.update_order_status(order_id, "completed")  # ← Could fail!
```

**Step 2 - Status update (can fail):** `woo_client.py:122-136`
```python
122 │ def update_order_status(self, order_id, status, retries=3):
123 │     """Update order status on WooCommerce (retries 3×)."""
    │     for i in range(retries):
    │         try:
    │             response = self.api.put(f"orders/{order_id}", {'status': status})
    │             return True
128 │         except Exception as e:
    │             if i < retries - 1:
    │                 time.sleep(2)
130 │     log_error("WOO", f"Failed to update order {order_id} status after {retries} retries")
131 │     return False  # ← Silently fails!
```

---

### 🟡 Issue 5: Unbounded Serial Queue
**File:** `hardware.py:131` (EspSerial.__init__)
```python
131 │ self._lines: queue.Queue[str] = queue.Queue()  # ← NO MAXSIZE!
```

**Enqueuing happens in:** `hardware.py:161`
```python
161 │ self._lines.put(line)
```

---

### 🟡 Issue 6: Config Write Not Atomic
**File:** `hardware.py:317-325` (_save_calibration_factor)
```python
317 │ def _save_calibration_factor(self, factor: float):
    │     """Write the counts-per-gram factor into hardware_config.json."""
319 │     try:
320 │         cfg = json.loads(_HW_CONFIG_PATH.read_text())
321 │         cfg["scale_calibration_factor"] = round(factor, 6)
322 │         _HW_CONFIG_PATH.write_text(json.dumps(cfg, indent=4))  # ← Direct overwrite!
```

**Similar pattern in other config saves:**
- `config.py` (if it has save methods)
- `progress.py` (OrderProgress disk writes)

---

### 🟠 Issue 7: Polling Paused Flag Race
**File:** `lcd_menu.py:1583-1590` (_poll daemon)
```python
1583 │ # Check if polling is paused
1584 │ with self._lock:
1585 │     paused = self._polling_paused  # ← Read protected
    │
1587 │ if paused:
1588 │     # Wait while paused, but keep checking for stop signal
1589 │     stop.wait(1.0)
    │     continue
```

**Meanwhile, main thread sets the flag:** `lcd_menu.py` (pause_polling method, search for it)
```python
# In error handler:
self._polling_paused = True  # ← Write without lock (after callback)
```

---

### 🟡 Issue 8: LCD Write Cache Not Locked
**File:** `lcd.py:55-70`
```python
55  │ def _write_row(self, row, text):
    │     """Write to LCD row with caching."""
    │     # No lock here!
    │     if text == self._cache[row]:
    │         return
    │     self._cache[row] = text  # ← Write without lock
```

**Called from main thread (protected):**
```python
# In lcd_menu.py render loop:
with self._lock:
    self._write_row(...)  # Caller has lock
```

**But also called from serial callback (unprotected!):**
```python
# In hardware.py _on_error_state callback:
if self.ui:
    try:
        self.ui.show_error(name, severity)  # ← No lock!
```

---

### 🟢 Issue 9: Cup Removal Timeout (Design)
**File:** `hardware.py:451-476` (wait_for_cup_removal)
```python
451 │ def wait_for_cup_removal(self):
452 │     """Wait for cup to be removed after drink is done."""
    │     log_info("HWINT", f"Drink done — waiting for cup removal...")
    │     # ...
468 │     while True:
469 │         self._cup_state_changed.wait(timeout=0.5)
470 │         self._cup_state_changed.clear()
471 │         if not self._cup_present:
472 │             log_info("HWINT", "Cup removed!")
473 │             # ...
476 │             return
    │
    │ # ← NO TIMEOUT! Loop runs forever until cup removed
```

---

### 🟡 Issue 10: Marquee Scroll Offset
**File:** `lcd_menu.py:349-374` (_draw_menu)
```python
349 │ def _draw_menu(self):
    │     # ... label changes ...
    │     label_width = len(label) - 4  # ← can become negative
    │     if label_width > 0:
    │         self._marq_offset = (self._marq_offset + 1) % label_width
    │     text = label[self._marq_offset : self._marq_offset + 20]  # ← potential issue
```

---

## Module Dependency Graph

```
main.py
├── config.py (load configs)
├── woo_client.py (REST API)
├── hardware.py ────────────────────────────┐
│   ├── serial (EspSerial)                  │
│   │   ├── Reader thread                   │ ← Callbacks run here!
│   │   └── Callbacks (no lock)             │
│   ├── NeopixelSerial                      │
│   └── GPIO setup                          │
├── orders.py                               │
│   ├── woo_client (heartbeat)              │
│   ├── hardware (make_drink)  ─────────────┘
│   └── progress (crash safety)
├── lcd_menu.py (UI) ──────────────┐
│   ├── encoder.py (GPIO polling)  │ ← Callbacks run here!
│   │   └── RotaryEncoder          │
│   ├── lcd.py (I2C)               │
│   ├── orders (process_order)     │
│   └── hardware (UI reference)    │
│       └── Injected for callbacks │
└── Other modules...
```

---

## Lock Acquisition Order

**CURRENT STATE:**

```
Main thread:
  _lock (50ms, ~5-20ms held)
    ├─ Read: _mode, _run_count, _cup_present
    ├─ Write: _dirty, _mode, _nav
    └─ Call draw methods (may access UI state)

Encoder thread:
  _lock (brief)
    ├─ Read: encoder state (internally)
    └─ Write: _mode, _run_count, _retry_drink

Serial reader threads:
  ❌ NO LOCK ACQUIRED
    ├─ Write: _cup_present (RACE!)
    └─ Call: ui.show_error() (which might try to write LCD)

Order polling thread:
  _lock (minimal, just to check pause flag)
    └─ Read: _polling_paused

NeopixelSerial:
  _lock (brief, just serialize serial writes)
    └─ Write: serial port
```

**RECOMMENDED CHANGE:**

Add `_cup_lock` for cup sensor state:
```python
def __init__(self):
    self._lock = threading.Lock()  # UI state (existing)
    self._cup_lock = threading.Lock()  # Cup sensor (NEW)
    self._cup_present = False
    self._cup_state_changed = threading.Event()
```

---

## Testing Checklist

- [ ] **Test carriage timeout:** Physically block stepper, attempt dispense
- [ ] **Test cup race:** Rapid cup insert/remove during polling
- [ ] **Test polling error:** Kill network, monitor LCD & logs
- [ ] **Test order duplication:** Inject network delay in status update
- [ ] **Test queue overflow:** Send garbage data to serial port (stress test)
- [ ] **Test config corruption:** Kill power during config write (test on VM)
- [ ] **Test pause flag race:** Enable polling, then trigger error & RETRY rapidly

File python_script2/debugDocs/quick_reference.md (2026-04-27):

# Barbot V2 - Quick Reference Guide

## What Is Barbot?

**An automated bartender** that:
1. Polls WooCommerce for drink orders
2. Parses recipes (spirits + mixers per drink)
3. Physically dispenses drinks:
   - **Stepper motor** (X-axis positioning, talks to HAT ESP32)
   - **Servo** (spirit bottle optic positioning, talks to HAT ESP32)
   - **Peristaltic pumps** (mixers, talks to pump ESP32)
   - **Scale/HX711** (auto-fill by weight, talks to pump ESP32)
   - **Cup sensor** (light curtain, detected by HAT ESP32)
   - **Neopixel LEDs** (animations, talks to neopixel ESP32)
4. Shows status on 4x20 LCD + rotary encoder UI

---

## Thread Organization (6 Active Threads)

| Thread | Role | Spawned | Lock | Risk |
|---|---|---|---|---|
| **Main (UI)** | 50 ms render loop | startup | `_lock` | ✅ Low |
| **Encoder** | 2 kHz GPIO polling | startup | `_lock` (callback) | 🟠 Med |
| **Serial HAT** | Read ESP32 cup/error/homing | startup | None! | 🔴 High |
| **Serial Pump** | Read ESP32 scale/fill events | startup | None! | 🔴 High |
| **Order Polling** | Fetch & process orders (blocking) | enter_run | Minimal | 🟠 Med |
| **Heartbeat** | Ping WooCommerce every 15s | process_order | None | ✅ Low |

### The Problem: Serial Readers Don't Use Locks

Serial reader threads (HAT & Pump ESP32) fire callbacks **WITHOUT acquiring `_lock`**:
```python
# In serial reader thread:
if "[cup] PRESENT" in line:
    self._on_cup_state(True)  # ← Called directly, NO LOCK!
        └─ self._cup_present = True  # Direct write to shared state!
```

While main thread reads under lock:
```python
# In main thread render loop:
with self._lock:
    if self._cup_present:  # ← Read under lock
        # ...
```

**Result:** Potential race condition (CPython GIL makes it *unlikely* but not guaranteed).

---

## Critical Issues & Risks

### 🔴 **CRITICAL: Carriage Collision (Timing Bug)**

**File:** `hardware.py:534-548` (_sync method)

**The Bug:**
```python
def _sync(self, timeout=30.0):
    self._esp.send(f"G0 X{self.x_position}")
    try:
        self._esp.wait_for(["Move done"], timeout=30)
    except TimeoutError:
        print("[HW] WARNING: timed out")
        # ← CONTINUES ANYWAY! This is the problem.
```

**Scenario:**
1. Carriage moves toward position 3000
2. Mechanical jam → move stalls
3. Timeout after 30s → function returns
4. **Servo opens and pours while carriage is still mid-transit**
5. Collision + spilled alcohol + broken hardware

**Fix:** Raise exception instead of continuing:
```python
except TimeoutError:
    raise HardwareError(f"Carriage move timed out after {timeout}s")
```

---

### 🟠 **HIGH: Cup Sensor Race Condition**

**File:** `hardware.py:355-378` (_on_cup_state_changed)

**The Bug:**
```python
# Serial reader thread (no lock):
def _on_cup_state_changed(self, present: bool):
    self._cup_present = present  # ← Unprotected write!

# Main thread (with lock):
with self._lock:
    if self._cup_present:  # ← Read protected, but write is not!
        # ...
```

**Why It Matters:**
- Cup detection is critical (triggers drink dispensing)
- Stale read = wrong cup state = dispensing without cup detected
- Race window very small but real

**Fix:**
```python
def _on_cup_state_changed(self, present: bool):
    with self._cup_lock:  # ← NEW
        self._cup_present = present
    self._cup_state_changed.set()
```

---

### 🟠 **MEDIUM: Polling Loop Silent Failure**

**File:** `lcd_menu.py:1600-1610` (_poll daemon)

**The Bug:**
```python
def _poll():
    while not stop.is_set():
        try:
            pending = self.woo.fetch_all(...)  # Could raise exception
        except Exception:
            pass  # ← Silently swallows errors!
        
        stop.wait(5)  # Sleep & retry
```

**Scenario:**
1. Network error in `fetch_all()` → exception
2. Caught & silently ignored
3. Poll loop sleeps 5 seconds
4. **User has no idea polling failed**
5. Orders not fetched, customers angry

**Fix:** Add error escalation:
```python
error_count = 0
while True:
    try:
        pending = fetch_all(...)
        error_count = 0
    except Exception as e:
        error_count += 1
        if error_count > 3:
            ui.show_network_error()
```

---

### 🟠 **MEDIUM: Order Duplication Risk**

**File:** `orders.py:111-112` + `woo_client.py:130`

**The Bug:**
```python
# After all drinks made:
self.woo.update_order_status(order_id, "completed")  # Could fail!

# If network error → order stays "processing"
# Next poll cycle (5s later) → order re-fetched
# → Entire order remade again
```

**Mitigation:**
- `OrderProgress` prevents drink duplication **within same order**
- But doesn't prevent re-processing same order entirely

**Fix:** Track processed order IDs:
```python
_processed_orders = set()
for order in pending:
    if order['id'] in _processed_orders:
        continue  # Skip already-processed
    _processed_orders.add(order['id'])
    process_order(order)
```

---

### 🟡 **MEDIUM: Unbounded Serial Queue**

**File:** `hardware.py:131` (queue.Queue initialization)

**The Bug:**
```python
self._lines = queue.Queue()  # ← No maxsize!
```

If serial reader gets stuck enqueuing (e.g., garbage data):
- Queue grows unbounded
- Eventually: **Out of Memory → Process killed**

**Fix:**
```python
self._lines = queue.Queue(maxsize=1000)
```

---

### 🟡 **MEDIUM: Config Write Not Atomic**

**File:** `config.py` + `hardware.py:322` (save_json)

**The Bug:**
```python
def save_json(path, data):
    with open(path, 'w') as f:
        json.dump(data, f)  # ← Direct overwrite, no atomicity
```

**Scenario:**
1. Writing config file
2. Power loss mid-write
3. File is corrupted (partial JSON)
4. **Next startup:** `json.load()` raises `JSONDecodeError`
5. **Application won't start**

**Fix:**
```python
import tempfile, os
with tempfile.NamedTemporaryFile(mode='w', delete=False, dir=path.parent) as tmp:
    json.dump(data, tmp)
    tmp_path = tmp.name
os.replace(tmp_path, path)  # ← Atomic on POSIX
```

---

## How the System Works (Happy Path)

```
TIME    ACTION
────────────────────────────────────────────────────────────────────
0s      Order polling daemon fetches "processing" orders from WooCommerce
        Found: Order #123 (2 drinks)
        
        Calls orders.process_order(#123)
        ├─ Spawns heartbeat thread (pings WooCommerce every 15s)
        │
        ├─ Drink 1: Margarita (2 oz tequila + 1 oz lime juice)
        │  ├─ UI shows "Mixing 1/2: Margarita"
        │  ├─ hardware.make_drink()
        │  │  ├─ wait_for_cup() [blocks until cup detected via serial]
        │  │  ├─ dispense_spirit(tequila_slot, 2oz)
        │  │  │  ├─ move_x(tequila_position)
        │  │  │  ├─ servo.open() + pour + servo.close()
        │  │  │  └─ settle delay
        │  │  ├─ dispense_mixer(lime_juice, 1oz)
        │  │  │  ├─ move_x(mixer_position)
        │  │  │  ├─ scale.tare()
        │  │  │  ├─ auto_fill(pump_n, 1oz) [fills until scale reads 1oz]
        │  │  │  └─ [FILL_END] received from ESP32
        │  │  ├─ move_to_idle()
        │  │  └─ wait_for_cup_removal() [blocks until cup removed or 5 min timeout]
        │  ├─ progress.drink_done() [write to disk: drink 1 complete]
        │
5s      ├─ Drink 2: ... [repeat]
        │
10s     ├─ Order complete, all drinks done
        ├─ woo.update_order_status(#123, "completed")
        │
        └─ Order polling resumes, fetches next order
```

---

## What Works Well ✅

- **Order processing is idempotent** (OrderProgress file prevents re-making same drink on crash)
- **Serial communication is robust** (handles partial frames, ANSI codes, etc.)
- **UI is responsive** (50 ms render loop, locks held briefly)
- **Heartbeat prevents WooCommerce re-polling** (15s ping during mixing)
- **Cup sensor debounced** (quadrature-like state machine for bounces)

---

## What Can Break ⚠️

1. **Carriage/servo collision** ← Most dangerous, can destroy hardware
2. **Cup sensor state race** ← Unlikely but possible (GIL-dependent)
3. **Silent polling failure** ← Network issues hidden from user
4. **Order duplication** ← Network latency can cause remakes
5. **Startup failure** ← Power loss during config write corrupts file

---

## Recommended Fixes (Priority Order)

### CRITICAL (Safety)
- [ ] Change `_sync()` timeout to raise exception (prevent collision)
- [ ] Add explicit lock to `_on_cup_state_changed()` (avoid race)

### HIGH (Reliability)
- [ ] Add maxsize to serial queue (prevent memory leak)
- [ ] Implement order deduplication (prevent remakes)
- [ ] Use atomic writes for config files

### MEDIUM (Robustness)
- [ ] Handle polling exception escalation (show error on LCD)
- [ ] Track processed order IDs across restarts

---

## Testing the Problems

### Test 1: Carriage Collision Risk
```python
# In hardware.py move_x(), change timeout to 5 seconds (instead of 30)
# Physically block the carriage
# Try to dispense → should see timeout & potential collision
# Fix: Should raise HardwareError instead
```

### Test 2: Cup Sensor Race
```python
# Rapid cup insert/remove while polling running
# Check if system ever misses cup detection
# Current: Very unlikely due to GIL
# Fixed: Would be guaranteed safe
```

### Test 3: Order Duplication
```python
# Introduce network delay in update_order_status() (e.g., sleep 30s)
# Let it timeout (3 retries * 2s = 6s, then give up)
# Next poll cycle will re-fetch & remake order
# Fix: Add order ID tracking
```

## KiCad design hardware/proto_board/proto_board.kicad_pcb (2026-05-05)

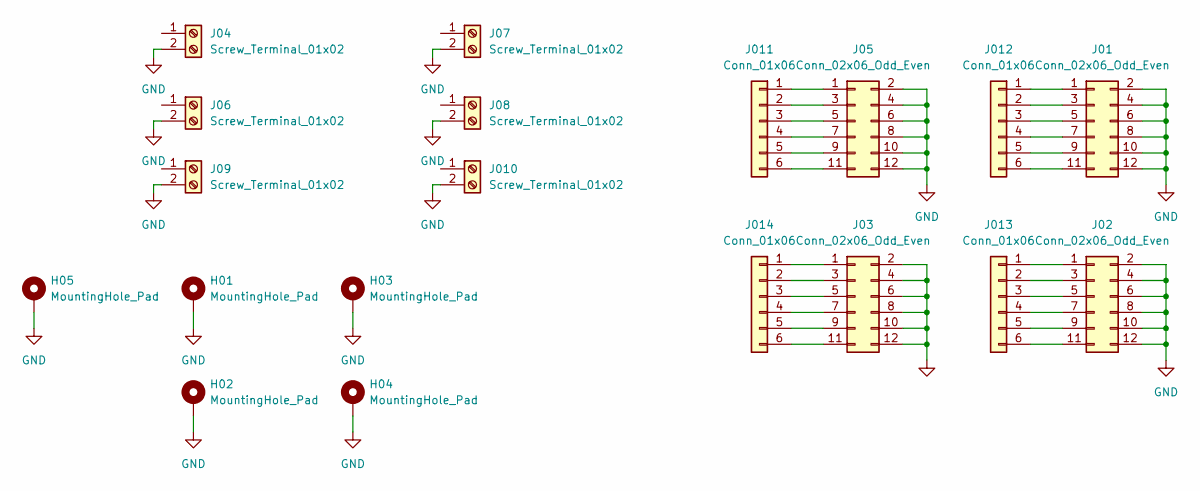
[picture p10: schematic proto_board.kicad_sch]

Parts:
H01, H02, H03, H04, H05: MountingHole_Pad; MountingHole_3.2mm_M3_Pad_Via
J01, J02, J03, J05: Conn_02x06_Odd_Even; PinSocket_2x06_P2.54mm_Vertical
J04, J06, J07, J08, J09, J010: Screw_Terminal_01x02; TerminalBlock_MetzConnect_Type055_RT01502HDWU_1x02_P5.00mm_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
J011, J012, J013, J014: Conn_01x06; 6Pin

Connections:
GND: H01.1 (1_1), H02.1 (1_1), H03.1 (1_1), H04.1 (1_1), H05.1 (1_1), J01.2, J01.4, J01.6, J01.8, J01.10, J01.12, J02.2, J02.4, J02.6, J02.8, J02.10, J02.12, J03.2, J03.4, J03.6, J03.8, J03.10, J03.12, J04.2 (Pin_2_2), J05.2, J05.4, J05.6, J05.8, J05.10, J05.12, J06.2 (Pin_2_2), J07.2 (Pin_2_2), J08.2 (Pin_2_2), J09.2 (Pin_2_2), J010.2 (Pin_2_2)
unnamed: J01.1, J012.1
unnamed: J01.3, J012.2
unnamed: J01.5, J012.3
unnamed: J01.7, J012.4
unnamed: J01.9, J012.5
unnamed: J01.11, J012.6
unnamed: J05.1, J011.1
unnamed: J05.3, J011.2
unnamed: J05.5, J011.3
unnamed: J05.7, J011.4
unnamed: J05.9, J011.5
unnamed: J05.11, J011.6
unnamed: J02.1, J013.1
unnamed: J02.3, J013.2
unnamed: J02.5, J013.3
unnamed: J02.7, J013.4
unnamed: J02.9, J013.5
unnamed: J02.11, J013.6
unnamed: J03.1, J014.1
unnamed: J03.3, J014.2
unnamed: J03.5, J014.3
unnamed: J03.7, J014.4
unnamed: J03.9, J014.5
unnamed: J03.11, J014.6

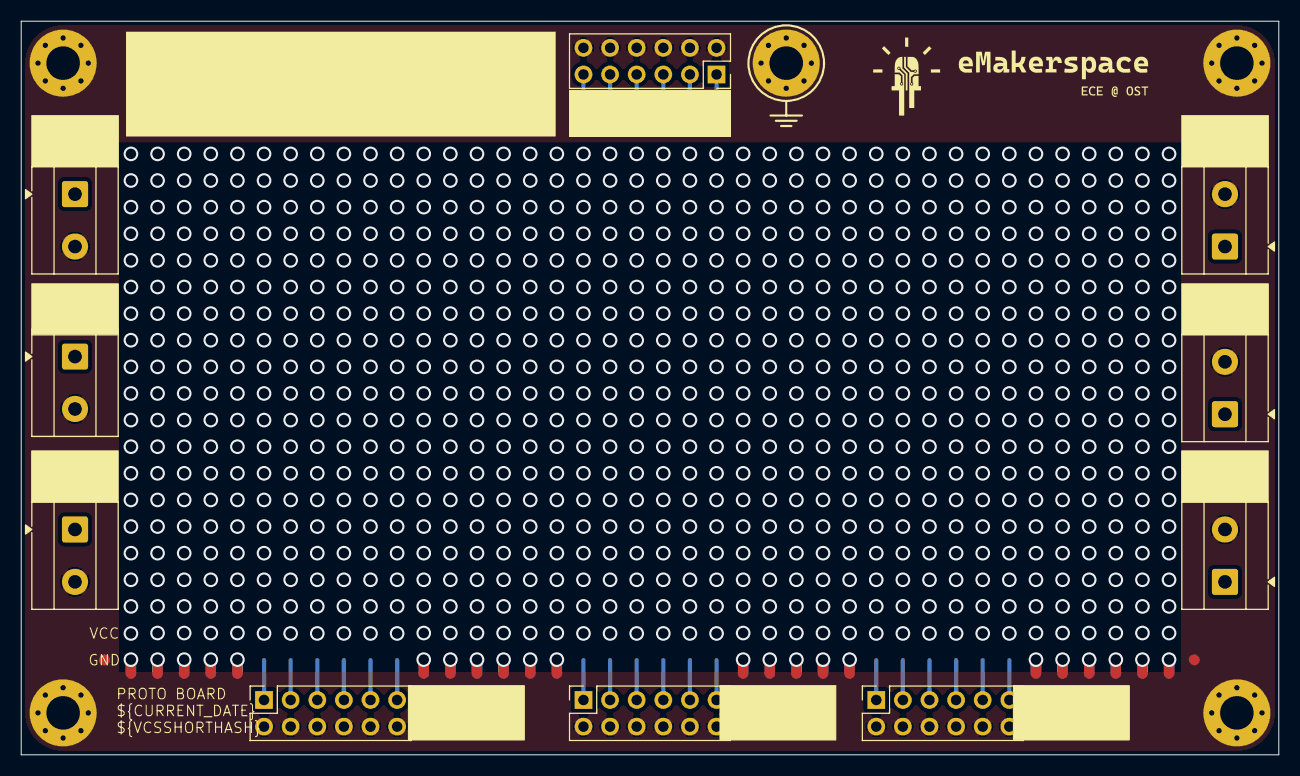
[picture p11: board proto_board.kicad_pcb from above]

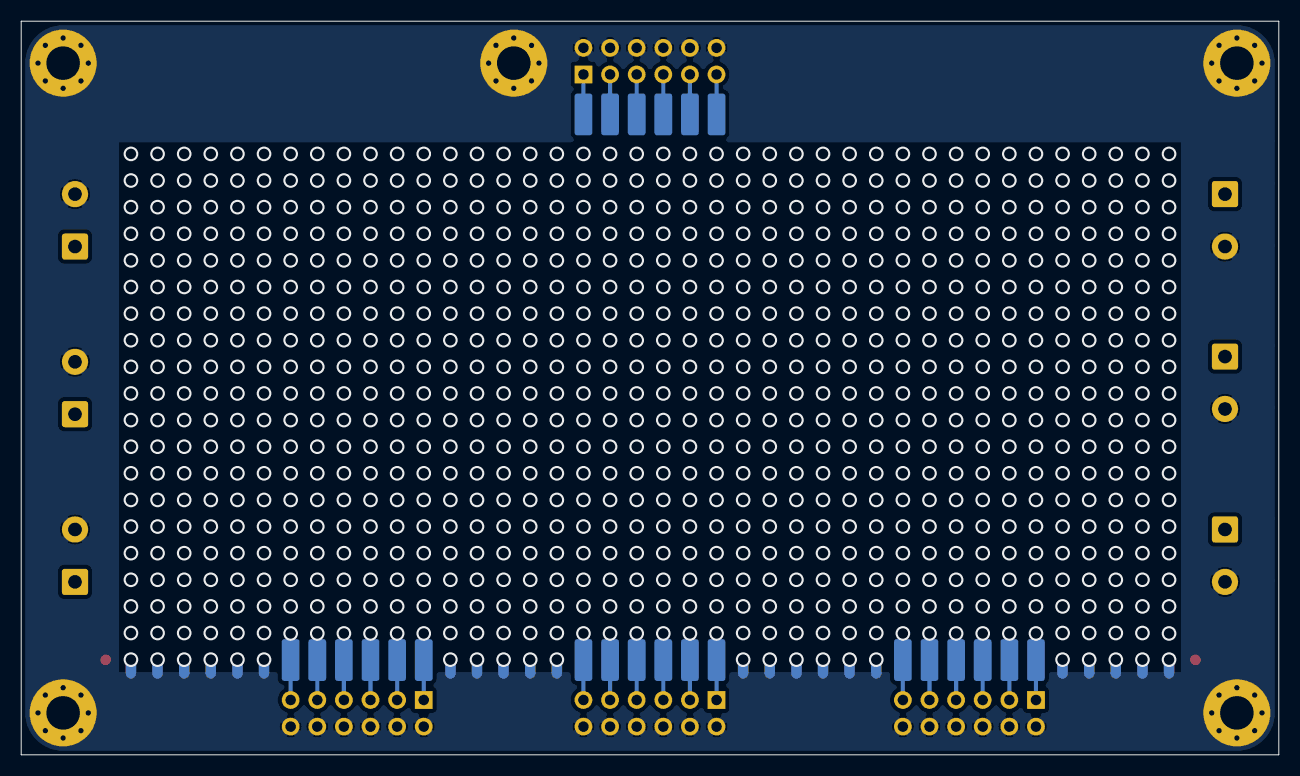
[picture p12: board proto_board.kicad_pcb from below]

Board: 2 copper layers, 120.0 x 70.0 mm, 19 parts (4 on the bottom side), 25 nets.

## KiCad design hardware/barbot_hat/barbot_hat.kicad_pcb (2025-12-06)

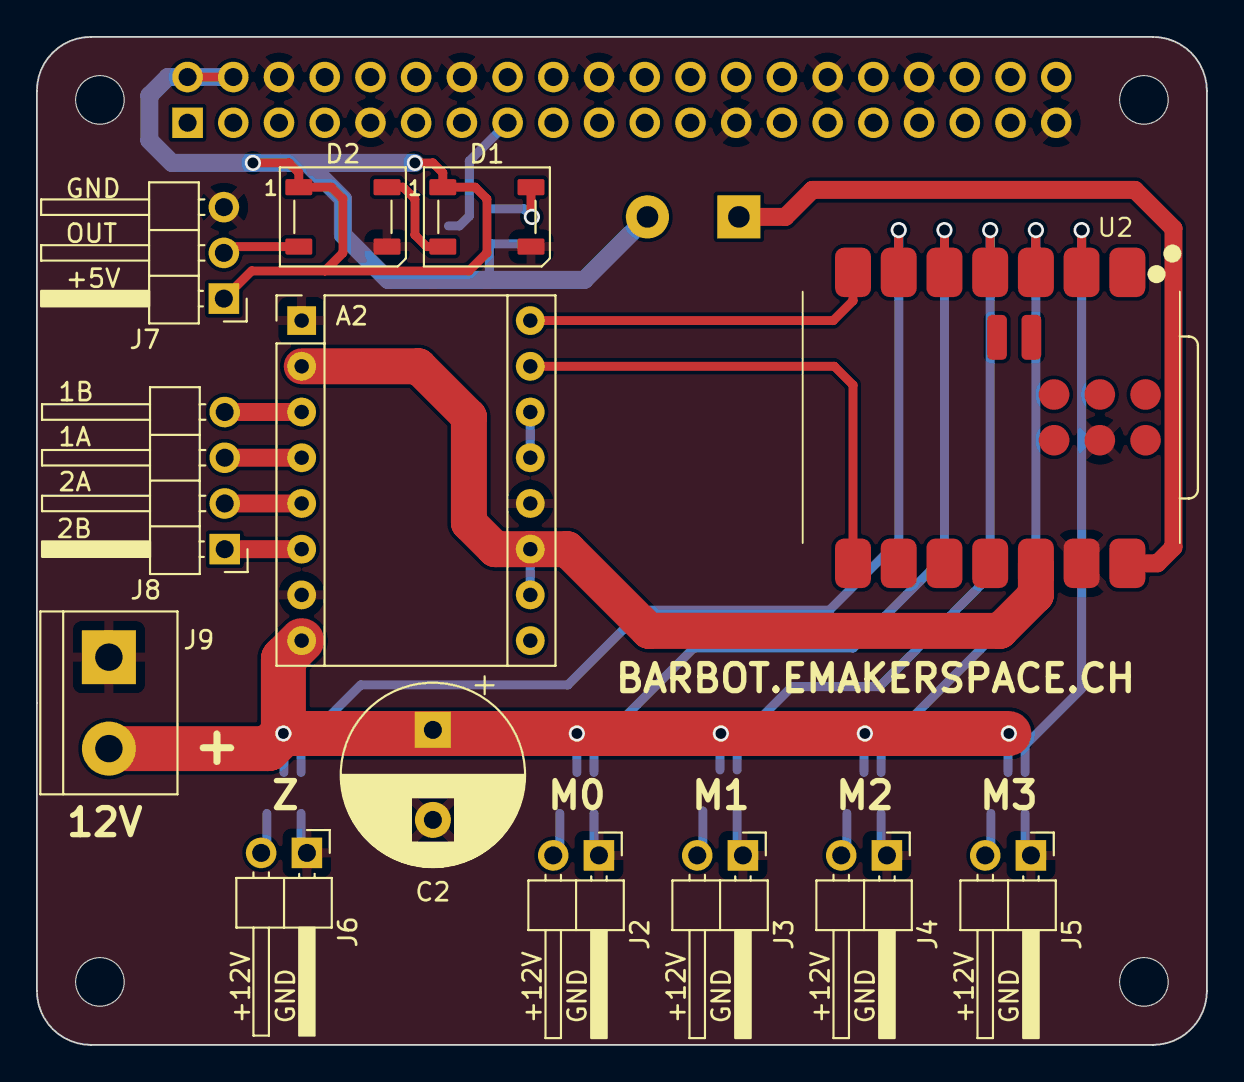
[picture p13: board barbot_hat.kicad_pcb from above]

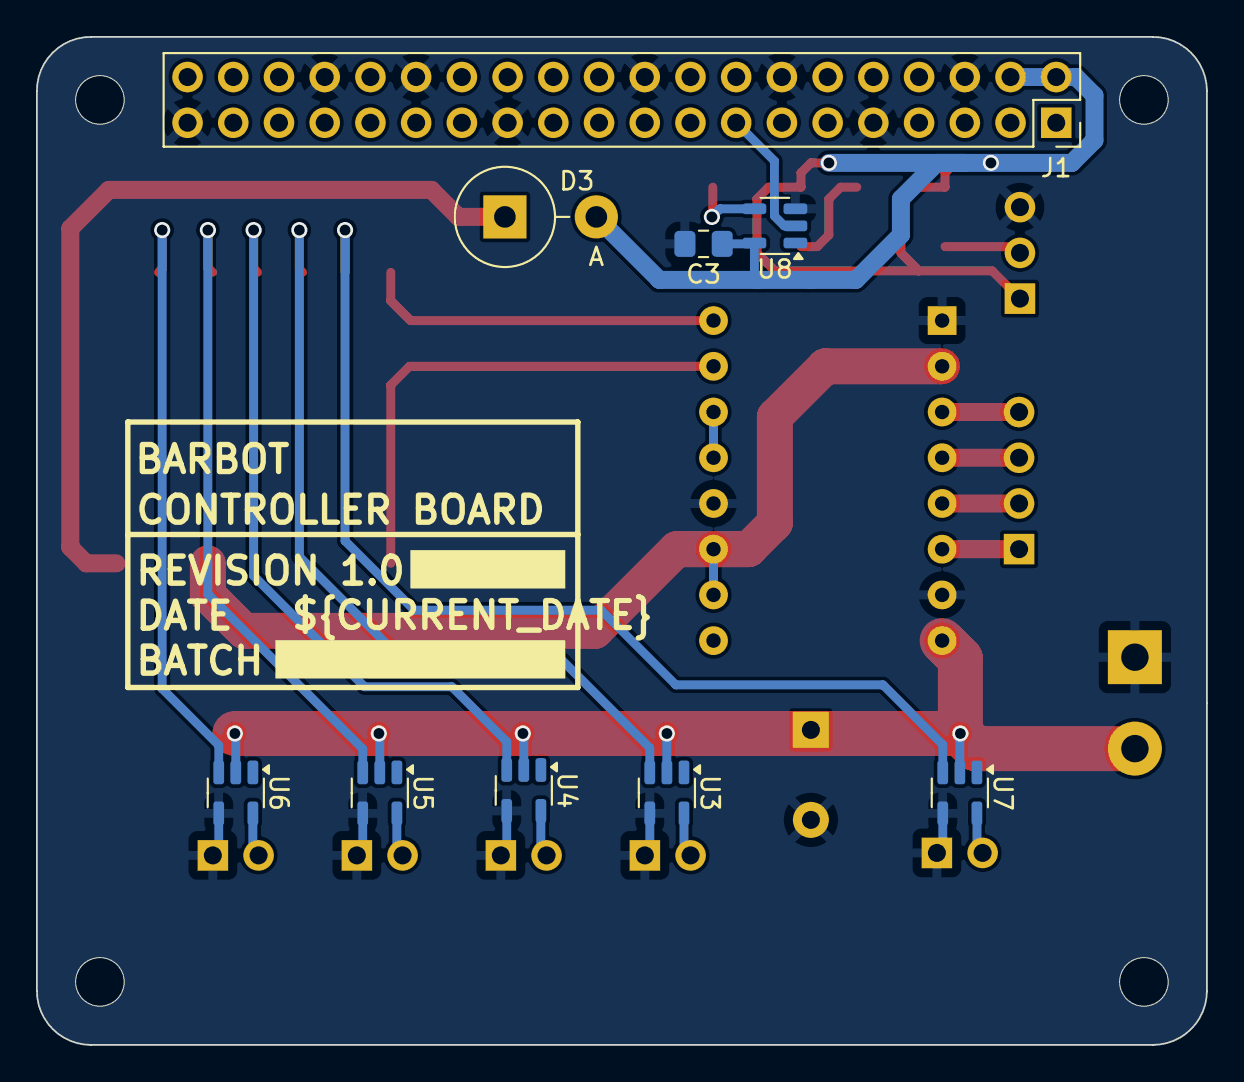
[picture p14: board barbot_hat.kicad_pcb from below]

Board: 2 copper layers, 65.0 x 56.0 mm, 26 parts (9 on the bottom side), 26 nets.

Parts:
A2: Pololu_Breakout_A4988; Pololu_Breakout-16_15.2x20.3mm
C2: C_Polarized; CP_Radial_D10.0mm_P5.00mm
C3: C; C_0805_2012Metric_Pad1.18x1.45mm_HandSolder
D1, D2: WS2812B; LED_WS2812B_PLCC4_5.0x5.0mm_P3.2mm
D3: D; D_DO-27_P5.08mm_Vertical_AnodeUp
J1: GPIO; PinSocket_2x20_P2.54mm_Vertical
J2, J3, J4, J5, J6: Conn_01x02; PinHeader_1x02_P2.54mm_Horizontal
J7: Conn_01x03; PinHeader_1x03_P2.54mm_Horizontal
J8: Conn_01x04; PinHeader_1x04_P2.54mm_Horizontal
J9: Screw_Terminal_01x02; TerminalBlock_bornier-2_P5.08mm
MH1, MH2, MH3, MH4: MountingHole_2.7mm_M2.5
U2: XIAO-ESP32C3-SMD
U3, U4, U5, U6, U7: MCP1416; SOT-23-5
U8: SN74LV1T34DBV; SOT-23-5

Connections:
+3V3: A2.2 (VDD), A2.10 (MS1), A2.11 (MS2), U2.12 (3V3)
+5V: C3.1, D1.1 (VDD), D2.1 (VDD), D3.2 (A), J1.2, J1.4, J7.1, U8.5 (VCC)
+12V: A2.8 (VMOT), C2.1, J9.2, U3.2 (Vdd), U4.2 (Vdd), U5.2 (Vdd), U6.2 (Vdd), U7.2 (Vdd)
/1A: A2.4 (1A), J8.3
/1B: A2.3 (1B), J8.4
/2A: A2.5 (2A), J8.2
/2B: A2.6 (2B), J8.1
/GPIO22 / NEOPIXEL_IN: J1.15, U8.2 (A)
/MOTOR_X_DIR: A2.16 (DIR), U2.7 (GPIO21)
/MOTOR_X_STEP: A2.15 (STEP), U2.8 (GPIO20)
/MOTOR_Z: U2.6 (GPIO7), U7.3 (IN)
/NEOPIXEL_OUT: D2.2 (DOUT), J7.2
/PUMP_CTRL0: U2.5 (GPIO6), U3.3 (IN)
/PUMP_CTRL1: U2.4 (GPIO5), U4.3 (IN)
/PUMP_CTRL2: U2.3 (GPIO4), U5.3 (IN)
/PUMP_CTRL3: U2.2 (GPIO3), U6.3 (IN)
GND: A2.1 (GND), A2.7 (GND), A2.12 (MS3), C2.2, C3.2, D1.3 (VSS), D2.3 (VSS), J1.6, J1.9, J1.14, J1.20, J1.25, J1.30, J1.34, J1.39, J2.1, J3.1, J4.1, J5.1, J6.1, J7.3, J9.1, U2.13 (GND), U2.20 (GND), U3.4 (GND), U4.4 (GND), U5.4 (GND), U6.4 (GND), U7.4 (GND), U8.3 (GND)
unnamed: A2.13 (~RESET), A2.14 (~SLEEP)
unnamed: D1.4 (DIN), U8.4 (Y)
unnamed: D1.2 (DOUT), D2.4 (DIN)
unnamed: D3.1 (K), U2.14 (5V)
unnamed: J2.2, U3.5 (OUT)
unnamed: J3.2, U4.5 (OUT)
unnamed: J4.2, U5.5 (OUT)
unnamed: J5.2, U6.5 (OUT)
unnamed: J6.2, U7.5 (OUT)

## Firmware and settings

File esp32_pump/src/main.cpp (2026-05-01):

#include <Arduino.h>
#include <Preferences.h>

// ---------------------------------------------------------------------------
// Pin assignments
// ---------------------------------------------------------------------------
#define HX711_CLK  13
#define HX711_DATA 14

// L298N pump channels (IN1/IN2 per pump)
// Pump index 0: GPIO27, GPIO26
// Pump index 1: GPIO33, GPIO25 (reversed polarity)
// Pump index 2: GPIO23, GPIO22 (reversed polarity)
// Pump index 3: GPIO18, GPIO19 (reversed polarity)
static const int PUMP_PIN_A[4] = {27, 33, 23, 18};
static const int PUMP_PIN_B[4] = {26, 25, 22, 19};
static bool pumpActive[4] = {false, false, false, false};
static uint32_t pumpOffAtMs[4] = {0, 0, 0, 0};

// ---------------------------------------------------------------------------
// Fill constants
// ---------------------------------------------------------------------------
#define STOP_FRACTION  0.98f
#define DRAIN_WAIT_MS  2000     // ms to wait after fill before signalling done

// ---------------------------------------------------------------------------
// Forward declarations
// ---------------------------------------------------------------------------
static void pumpStop(int pumpIdx);
static void pumpReverse(int pumpIdx);

// ---------------------------------------------------------------------------
// HX711 — bit-bang driver
// ---------------------------------------------------------------------------
class HX711 {
public:
    HX711(int clk, int data) : _clk(clk), _data(data) {}

    void begin() {
        pinMode(_clk,  OUTPUT);
        pinMode(_data, INPUT);
        digitalWrite(_clk, LOW);
        delay(500);
    }

    bool isReady() { return digitalRead(_data) == LOW; }

    int32_t read() {
        if (!_waitReady(1000)) return INT32_MIN;
        int32_t v = 0;
        for (int i = 0; i < 24; i++) {
            digitalWrite(_clk, HIGH); delayMicroseconds(1);
            v = (v << 1) | (digitalRead(_data) ? 1 : 0);
            digitalWrite(_clk, LOW);  delayMicroseconds(1);
        }
        // extra clock pulse selects gain 128 for next read
        digitalWrite(_clk, HIGH); delayMicroseconds(1);
        digitalWrite(_clk, LOW);
        if (v & 0x800000) v |= 0xFF000000;  // sign-extend 24-bit
        return v;
    }

private:
    int _clk, _data;

    bool _waitReady(uint32_t timeout_ms) {
        uint32_t t0 = millis();
        while (digitalRead(_data) == HIGH) {
            if (millis() - t0 > timeout_ms) return false;
            delayMicroseconds(10);
        }
        return true;
    }
};

// ---------------------------------------------------------------------------
// Kalman filter (1-D, constant process/measurement noise)
// ---------------------------------------------------------------------------
class Kalman {
public:
    Kalman() : _estimate(0), _errorCov(1000.0f), _initialized(false) {}

    void reset(float initial) {
        _estimate    = initial;
        _errorCov    = 1000.0f;
        _initialized = true;
    }

    float update(float z) {
        if (!_initialized) reset(z);
        const float Q = 500.0f, R = 2500.0f;
        float p  = _errorCov + Q;
        float k  = p / (p + R);
        _estimate  = _estimate + k * (z - _estimate);
        _errorCov  = (1.0f - k) * p;
        return _estimate;
    }

    float estimate()    const { return _estimate; }
    bool  initialized() const { return _initialized; }

private:
    float _estimate, _errorCov;
    bool  _initialized;
};

// ---------------------------------------------------------------------------
// Scale
// ---------------------------------------------------------------------------
class Scale {
public:
    static constexpr float DEFAULT_CPG = 27.06f;

    Scale(HX711& hx711) : _hx711(hx711), _tareOffset(0), _cpg(DEFAULT_CPG) {}

    void begin() {
        _hx711.begin();
        _loadCalibration();
        Serial.println("[SCALE] ready");
        Serial.printf("[SCALE] DATA pin: %s\n", _hx711.isReady() ? "LOW (ready)" : "HIGH (not ready)");
    }

    // G3.1 — tare
    bool tare(int samples = 8) {
        int64_t sum = 0; int count = 0;
        for (int i = 0; i < samples; i++) {
            int32_t raw = _hx711.read();
            if (raw != INT32_MIN) { sum += raw; count++; Serial.printf("[TARE] %d: %ld\n", i + 1, (long)raw); }
            else                  { Serial.printf("[TARE] %d: FAILED\n", i + 1); }
        }
        if (count < samples / 2) { Serial.printf("ERROR tare failed (%d/%d reads)\n", count, samples); return false; }
        _tareOffset = (int32_t)(sum / count);
        _kalman.reset(0.0f);
        Serial.printf("Scale tared (offset=%ld, %d/%d reads)\n", (long)_tareOffset, count, samples);
        return true;
    }

    // G3.2 W{g} — calibrate with known weight already on scale
    bool calibrate(float knownGrams) {
        int32_t raw = _hx711.read();
        if (raw == INT32_MIN) { Serial.println("ERROR calibration failed: no HX711 response"); return false; }
        float tared = (float)(raw - _tareOffset);
        if (fabsf(tared) < 1.0f) { Serial.println("ERROR calibration failed: reading near zero, tare first"); return false; }
        _cpg = tared / knownGrams;
        _saveCalibration();
        Serial.printf("Calibrated: %.4f counts/gram (tared=%.0f known=%.1fg)\n", _cpg, tared, knownGrams);
        return true;
    }

    // G3.3 F{cpg} — restore calibration factor from host
    void setCountsPerGram(float cpg) {
        _cpg = cpg;
        _saveCalibration();
        Serial.printf("Scale calibration restored: %.4f counts/gram\n", _cpg);
    }

    // G3 — Kalman-filtered weight reading
    float weightGrams(int samples = 3) {
        int64_t sum = 0; int count = 0;
        for (int i = 0; i < samples; i++) {
            int32_t raw = _hx711.read();
            if (raw != INT32_MIN) { sum += (raw - _tareOffset); count++; }
        }
        if (count == 0) return NAN;
        float measured = (float)(sum / count) / _cpg;
        // Re-seed the filter if it is far from the measurement so the first
        // read after a tare or a large weight change converges immediately.
        if (!_kalman.initialized() || fabsf(measured - _kalman.estimate()) > 50.0f)
            _kalman.reset(measured);
        return _kalman.update(measured);
    }

    // G3.4 N{n} — raw debug reads
    void debug(int n) {
        Serial.printf("[DBG] DATA pin: %s\n", _hx711.isReady() ? "LOW (ready)" : "HIGH (not ready)");
        for (int i = 0; i < n; i++) {
            uint32_t t0  = millis();
            int32_t  raw = _hx711.read();
            uint32_t dt  = millis() - t0;
            if (raw != INT32_MIN) Serial.printf("[DBG] %d  wait=%lums raw=%ld\n", i, (unsigned long)dt, (long)raw);
            else                  Serial.printf("[DBG] %d  TIMEOUT after %lums\n", i, (unsigned long)dt);
        }
        Serial.println("[DBG] done");
    }

    int32_t readRaw()       { return _hx711.read(); }
    int32_t tareOffset()    { return _tareOffset; }
    float   countsPerGram() { return _cpg; }

private:
    HX711&      _hx711;
    Kalman      _kalman;
    int32_t     _tareOffset;
    float       _cpg;
    Preferences _prefs;

    void _saveCalibration() {
        _prefs.begin("scale", false);
        _prefs.putFloat("cpg", _cpg);
        _prefs.end();
    }

    void _loadCalibration() {
        _prefs.begin("scale", true);
        _cpg = _prefs.getFloat("cpg", DEFAULT_CPG);
        _prefs.end();
        Serial.printf("[SCALE] loaded calibration: %.4f counts/gram\n", _cpg);
    }
};

// ---------------------------------------------------------------------------
// Fill loop — G4 I{pump} W{grams}
//


// ---------------------------------------------------------------------------

static void fillEnd(const char* reason, float dispensed, uint32_t elapsed, int pumpIdx) {
    pumpStop(pumpIdx);
    Serial.printf("[RETRACT_START]\n");
    Serial.flush();
    delay(600);
    pumpReverse(pumpIdx);
    delay(1000);
    pumpStop(pumpIdx);
    Serial.printf("[FILL_END] reason=%s dispensed=%.1fg duration=%lums\n",
                  reason, dispensed, (unsigned long)elapsed);
    Serial.flush();
}

static bool pumpValid(int pumpIdx) { return pumpIdx >= 0 && pumpIdx < 4; }

static void pumpStop(int pumpIdx) {
    if (!pumpValid(pumpIdx)) return;
    digitalWrite(PUMP_PIN_A[pumpIdx], LOW);
    digitalWrite(PUMP_PIN_B[pumpIdx], LOW);
    pumpActive[pumpIdx] = false;
    pumpOffAtMs[pumpIdx] = 0;
}

static void pumpStart(int pumpIdx) {
    if (!pumpValid(pumpIdx)) return;
    // Forward direction on L298N.
    digitalWrite(PUMP_PIN_A[pumpIdx], HIGH);
    digitalWrite(PUMP_PIN_B[pumpIdx], LOW);
    pumpActive[pumpIdx] = true;
}

static void pumpReverse(int pumpIdx) {
    if (!pumpValid(pumpIdx)) return;
    // Reverse direction on L298N.
    digitalWrite(PUMP_PIN_A[pumpIdx], LOW);
    digitalWrite(PUMP_PIN_B[pumpIdx], HIGH);
    pumpActive[pumpIdx] = true;
}

static void stopAllPumps() {
    for (int i = 0; i < 4; i++) pumpStop(i);
}

static void updatePumpSchedules() {
    uint32_t now = millis();
    for (int i = 0; i < 4; i++) {
        if (pumpActive[i] && pumpOffAtMs[i] != 0 && (int32_t)(now - pumpOffAtMs[i]) >= 0) {
            pumpStop(i);
        }
    }
}

static void runPumpTimed(int pumpIdx, uint32_t durationMs, bool wait) {
    if (!pumpValid(pumpIdx)) {
        Serial.println("ERROR invalid pump index");
        return;
    }
    if (durationMs == 0) {
        pumpStop(pumpIdx);
        Serial.printf("OK pump=%d stopped\n", pumpIdx);
        return;
    }
    pumpStart(pumpIdx);
    if (!wait) {
        pumpOffAtMs[pumpIdx] = millis() + durationMs;
        Serial.printf("OK pump=%d running_for=%lums\n", pumpIdx, (unsigned long)durationMs);
        return;
    }
    uint32_t t0 = millis();
    while ((millis() - t0) < durationMs) delay(2);
    pumpStop(pumpIdx);
    Serial.printf("OK pump=%d done\n", pumpIdx);
}

static void fillLoop(Scale& scale, int pumpIdx, float targetGrams) {
    const float cpg = scale.countsPerGram();
    if (cpg < 1.0f) {
        Serial.println("ERROR fill failed: scale not calibrated, run G3.2 first");
        return;
    }
    if (!pumpValid(pumpIdx)) {
        Serial.println("ERROR invalid pump index");
        return;
    }
    if (targetGrams <= 0.0f) {
        fillEnd("zero_target", 0.0f, 0, pumpIdx);
        return;
    }

    const float OUTLIER_THRESHOLD_G = 20.0f;
    const int   OUTLIER_TREND_COUNT = 8;
    const int   MAX_HX711_ERRORS    = 5;
    const float MIN_PROGRESS_G      = 1.0f;
    const int   NO_PROGRESS_LIMIT   = 50;
    const float RATE_WINDOW_G       = 10.0f;
    const int   RATE_WINDOW_SAMPLES = 120;
    const float FILL_TIMEOUT_MS     = 60000.0f;

    // Establish baseline before pump starts
    int64_t bSum = 0; int bCount = 0;
    for (int i = 0; i < 2; i++) {
        int32_t raw = scale.readRaw();
        if (raw != INT32_MIN) { bSum += (raw - scale.tareOffset()); bCount++; }
    }
    if (bCount == 0) { Serial.println("ERROR fill failed: HX711 not responding"); return; }

    float baseline = ((float)bSum / bCount) / cpg;
    float stopAt   = targetGrams * STOP_FRACTION;

    Kalman kalman;
    kalman.reset(baseline);

    Serial.printf("[FILL_START] pump=%d target=%.1fg stop_at=%.1fg baseline=%.2fg\n",
        pumpIdx, targetGrams, stopAt, baseline);

    uint32_t startMs = millis();
    pumpStart(pumpIdx);

    int   hx711Errors   = 0;
    float lastWeight    = baseline;
    int   noProgressCnt = 0;
    float outlierBuf[OUTLIER_TREND_COUNT] = {};
    int   outlierCount  = 0;
    float weightHistory[RATE_WINDOW_SAMPLES] = {};
    int   histIdx = 0, histCount = 0;
    float dispensed = 0.0f;
    uint32_t lastWeightLogMs = 0;

    while (true) {
        uint32_t elapsed = millis() - startMs;

        if ((float)elapsed >= FILL_TIMEOUT_MS) {
            fillEnd("timeout", dispensed, elapsed, pumpIdx);
            return;
        }

        int32_t raw = scale.readRaw();
        if (raw == INT32_MIN) {
            Serial.printf("[HX711] read error %d/%d\n", ++hx711Errors, MAX_HX711_ERRORS);
            if (hx711Errors >= MAX_HX711_ERRORS) {
                fillEnd("hx711_error", dispensed, elapsed, pumpIdx);
                return;
            }
            continue;
        }
        hx711Errors = 0;

        float weightG = (float)(raw - scale.tareOffset()) / cpg;

        // Outlier rejection with sustained-trend detection
        if (fabsf(weightG - kalman.estimate()) > OUTLIER_THRESHOLD_G) {
            outlierBuf[outlierCount % OUTLIER_TREND_COUNT] = weightG;
            outlierCount++;
            if (outlierCount >= OUTLIER_TREND_COUNT) {
                bool allAbove = true, allBelow = true;
                for (int i = 0; i < OUTLIER_TREND_COUNT; i++) {
                    if (outlierBuf[i] <= kalman.estimate()) allAbove = false;
                    if (outlierBuf[i] >= kalman.estimate()) allBelow = false;
                }
                if (allAbove || allBelow) {
                    float sorted[OUTLIER_TREND_COUNT];
                    memcpy(sorted, outlierBuf, sizeof(sorted));
                    for (int i = 0; i < OUTLIER_TREND_COUNT - 1; i++)
                        for (int j = i + 1; j < OUTLIER_TREND_COUNT; j++)
                            if (sorted[j] < sorted[i]) { float t = sorted[i]; sorted[i] = sorted[j]; sorted[j] = t; }
                    float median = sorted[OUTLIER_TREND_COUNT / 2];
                    Serial.printf("[TREND] t=%lums resetting Kalman to %.2fg\n", (unsigned long)elapsed, median);
                    kalman.reset(median);
                    outlierCount = 0;
                    continue;
                }
            }
            Serial.printf("[OUTLIER] t=%lums measured=%.2fg estimate=%.2fg — skipped\n",
                (unsigned long)elapsed, weightG, kalman.estimate());
            continue;
        }
        outlierCount = 0;

        float filtered = kalman.update(weightG);
        dispensed = baseline - filtered;
        if (dispensed < 0.0f) dispensed = 0.0f;

        // Periodic weight log (~1 Hz) so Python watchdog can reset its timer
        if (elapsed - lastWeightLogMs >= 1000) {
            Serial.printf("[FILL_WEIGHT] t=%lums w=%.1fg\n",
                          (unsigned long)elapsed, dispensed);
            lastWeightLogMs = elapsed;
        }

        // No-progress check
        if (fabsf(filtered - lastWeight) < MIN_PROGRESS_G) {
            if (++noProgressCnt >= NO_PROGRESS_LIMIT) {
                fillEnd("empty_or_blocked", dispensed, elapsed, pumpIdx);
                return;
            }
        } else {
            noProgressCnt = 0;
            lastWeight    = filtered;
        }

        // Sliding window rate check
        int slot = histIdx % RATE_WINDOW_SAMPLES;
        weightHistory[slot] = filtered;
        histIdx++;
        if (histCount < RATE_WINDOW_SAMPLES) histCount++;
        if (histCount >= RATE_WINDOW_SAMPLES) {
            float oldest = weightHistory[histIdx % RATE_WINDOW_SAMPLES];
            float change = fabsf(oldest - filtered);
            if (change < RATE_WINDOW_G) {
                fillEnd("pump_failure", dispensed, elapsed, pumpIdx);
                return;
            }
        }

        if (dispensed >= stopAt) {
            fillEnd("target_reached", dispensed, elapsed, pumpIdx);
            return;
        }
    }
}

// ---------------------------------------------------------------------------
// Globals
// ---------------------------------------------------------------------------
HX711 hx711(HX711_CLK, HX711_DATA);
Scale scale(hx711);

// ---------------------------------------------------------------------------
// Setup
// ---------------------------------------------------------------------------
void setup() {
    Serial.begin(115200);
    for (int i = 0; i < 4; i++) {
        pinMode(PUMP_PIN_A[i], OUTPUT);
        pinMode(PUMP_PIN_B[i], OUTPUT);
    }
    stopAllPumps();

    Serial.println("BarBot scale ESP32");
    scale.begin();
    Serial.println("Commands: G2 I{n} D{ms}  G2.1 I{n} D{ms}  G3  G3.1  G3.2 W{g}  G3.3 F{cpg}  G3.4 N{n}  G4 I{n} W{g}  M0");
}

// ---------------------------------------------------------------------------
// Command handler
// ---------------------------------------------------------------------------
void handleCommand(const String& line) {
    if (line == "G3") {
        float w = scale.weightGrams();
        if (isnan(w)) Serial.println("ERROR scale read failed");
        else          Serial.printf("Weight: %.2fg\n", w);

    } else if (line == "G3.1") {
        scale.tare();

    } else if (line.startsWith("G3.2")) {
        int i = line.indexOf('W');
        if (i < 0) { Serial.println("ERROR G3.2 requires W param"); return; }
        scale.calibrate(line.substring(i + 1).toFloat());

    } else if (line.startsWith("G3.3")) {
        int i = line.indexOf('F');
        if (i < 0) { Serial.println("ERROR G3.3 requires F param"); return; }
        scale.setCountsPerGram(line.substring(i + 1).toFloat());

    } else if (line.startsWith("G3.4")) {
        int i = line.indexOf('N');
        scale.debug(i >= 0 ? line.substring(i + 1).toInt() : 10);

    } else if (line.startsWith("G4")) {
        int iIdx = line.indexOf('I'), wIdx = line.indexOf('W');
        if (iIdx < 0 || wIdx < 0) { Serial.println("ERROR G4 requires I and W params"); return; }
        int   pumpIdx = line.substring(iIdx + 1).toInt();
        float grams   = line.substring(wIdx + 1).toFloat();
        fillLoop(scale, pumpIdx, grams);

    } else if (line.startsWith("G2.1")) {
        int iIdx = line.indexOf('I'), dIdx = line.indexOf('D');
        if (iIdx < 0 || dIdx < 0) { Serial.println("ERROR G2.1 requires I and D params"); return; }
        int pumpIdx = line.substring(iIdx + 1).toInt();
        uint32_t ms = (uint32_t)line.substring(dIdx + 1).toInt();
        runPumpTimed(pumpIdx, ms, true);

    } else if (line.startsWith("G2")) {
        int iIdx = line.indexOf('I'), dIdx = line.indexOf('D');
        if (iIdx < 0 || dIdx < 0) { Serial.println("ERROR G2 requires I and D params"); return; }
        int pumpIdx = line.substring(iIdx + 1).toInt();
        uint32_t ms = (uint32_t)line.substring(dIdx + 1).toInt();
        runPumpTimed(pumpIdx, ms, false);

    } else if (line == "M0" || line == "M0.1") {
        stopAllPumps();
        Serial.println("OK stopped");

    } else if (line == "M115") {
        Serial.println("FIRMWARE_NAME:barbot-scale FIRMWARE_VERSION:1.0");

    } else {
        Serial.printf("ERROR unknown command: %s\n", line.c_str());
    }
}

// ---------------------------------------------------------------------------
// Loop
// ---------------------------------------------------------------------------
String inputBuf;

void loop() {
    while (Serial.available()) {
        char c = Serial.read();
        if (c == '\n' || c == '\r') {
            inputBuf.trim();
            if (inputBuf.length() > 0) handleCommand(inputBuf);
            inputBuf = "";
        } else {
            inputBuf += c;
        }
    }
    updatePumpSchedules();
}

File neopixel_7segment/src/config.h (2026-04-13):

#pragma once
#include <cstdint>

// All hardware pin assignments and timing constants in one place.
// Only this file needs to change when adapting to different hardware.
namespace cfg {

    // Common-anode enable pins: index 0 = ones (10⁰), index 1 = tens (10¹)
    constexpr uint8_t ENABLE[2]  = { 21, 22 };

    // Segment pins a–g, shared (multiplexed) between both displays
    //   index: 0=a  1=b  2=c  3=d  4=e  5=f  6=g
    //   layout:
    //       aaa
    //      f   b
    //      f   b
    //       ggg
    //      e   c
    //      e   c
    //       ddd
    constexpr uint8_t SEGMENT[7] = { 18, 19, 4, 2, 16, 5, 17 };

    // Multiplexer on-time per display per cycle (µs).
    // 2 000 µs × 2 displays = 4 ms cycle = 250 Hz refresh — flicker-free.
    constexpr uint32_t SLOT_US = 2000;

    // Brightness fade timing
    constexpr uint32_t HOLD_MS = 600;   // hold at full brightness before fading
    constexpr uint32_t FADE_MS = 300;   // duration of each fade-out / fade-in

    // 7-segment digit encoding: bit 0 = segment a … bit 6 = segment g.
    // A set bit means that segment is ON for that digit.
    //
    //  bit index:  6 5 4 3 2 1 0
    //  segment:    g f e d c b a
    constexpr uint8_t DIGIT_ENCODING[10] = {
        0b0111111,  // 0: a b c d e f
        0b0000110,  // 1: b c
        0b1011011,  // 2: a b d e g
        0b1001111,  // 3: a b c d g
        0b1100110,  // 4: b c f g
        0b1101101,  // 5: a c d f g
        0b1111101,  // 6: a c d e f g
        0b0000111,  // 7: a b c
        0b1111111,  // 8: a b c d e f g
        0b1101111,  // 9: a b c d f g
    };

    // -----------------------------------------------------------------------
    // WS2812 LED strip — three physically distinct segments on one data line
    //
    //   [0 … 42]   BAR    – 43 LEDs, horizontal bar
    //   [43 … 58]  RING   – 16 LEDs, circular ring
    //   [59 … 86]  U      – 28 LEDs, U-shape (left leg → bottom → right leg)
    // -----------------------------------------------------------------------
    constexpr uint8_t  LED_PIN   = 13;
    constexpr uint16_t LED_COUNT = 87;   // 43 + 16 + 28

    // Segment start indices and lengths
    constexpr uint16_t BAR_START  =  0;
    constexpr uint16_t BAR_LEN    = 43;
    constexpr uint16_t RING_START = 43;
    constexpr uint16_t RING_LEN   = 16;
    constexpr uint16_t U_START    = 59;
    constexpr uint16_t U_LEN      = 28;

    // Target LED refresh rate (fps). tick() is a no-op if called more often.
    constexpr uint32_t LED_FPS   = 30;
    constexpr uint32_t LED_FRAME_MS = 1000 / LED_FPS;   // ~33 ms

    // Idle animation phase durations (ms)
    // Bar phases
    constexpr uint32_t LED_DUR_RAINBOW_WAVE   = 20000;
    constexpr uint32_t LED_DUR_COMET          = 20000;
    constexpr uint32_t LED_DUR_TWINKLE        = 20000;
    constexpr uint32_t LED_DUR_BREATHING      = 20000;
    constexpr uint32_t LED_DUR_THEATER_CHASE  = 20000;
    constexpr uint32_t LED_DUR_COLOR_WIPE     = 20000;
    constexpr uint32_t LED_DUR_SCANNER        = 20000;
    // Ring phases
    constexpr uint32_t LED_DUR_RING_SPIN      = 20000;
    constexpr uint32_t LED_DUR_RING_PULSE     = 20000;
    constexpr uint32_t LED_DUR_RING_CYLON     = 20000;
    // U-shape phases
    constexpr uint32_t LED_DUR_U_FILL         = 20000;
    constexpr uint32_t LED_DUR_U_BOUNCE       = 20000;
    constexpr uint32_t LED_DUR_U_METEOR       = 20000;

} // namespace cfg

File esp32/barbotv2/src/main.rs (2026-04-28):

#![no_std]
#![no_main]

use embassy_executor::Spawner;
use esp_backtrace as _;
use esp_hal::clock::CpuClock;
use esp_hal::gpio::{Input, InputConfig};
use esp_hal::time::Rate;
use esp_hal::usb_serial_jtag::UsbSerialJtag;
use log::info;
use stepper::Stepper;

use crate::cmd::{CmdChannel, ServoCmdSignal, StepperCmdSignal, StopChannel};
use portable_atomic::AtomicI32;

esp_bootloader_esp_idf::esp_app_desc!();

pub mod cmd;
pub mod led;
pub mod rmt;
pub mod stepgen;
pub mod stepper;
pub mod tasks;
pub mod utils;

extern crate alloc;

// Microstepping factor: hardware is configured for 1/4 steps.
pub const MICROSTEPS: f64 = 4.0;

// Safety margin near slot 4/5 where servo opening is allowed.
// Forbidden zone is only the middle span between slots after this margin.
pub const SERVO_ZONE_BUFFER: i32 = 25;

pub const STEPPER_NORMAL_ACCEL_SPEED: stepper::AccelSpeedConfig = stepper::AccelSpeedConfig::zero()
    .with_acceleration(3000.0 * MICROSTEPS)
    .with_max_speed(3800.0 * MICROSTEPS);

const STEPPER_HOMING_ACCEL_SPEED: stepper::AccelSpeedConfig = stepper::AccelSpeedConfig::zero()
    .with_acceleration(2000.0 * MICROSTEPS)
    .with_max_speed(100.0 * MICROSTEPS);

static STOP_CHANNEL: StopChannel = StopChannel::new();
static STEPPER_CMD_SIG: StepperCmdSignal = StepperCmdSignal::new();
static CMD_CHANNEL: CmdChannel = CmdChannel::new();
static SERVO_CMD_SIG: ServoCmdSignal = ServoCmdSignal::new();
// Track current stepper X position for servo forbidden zone checking
static STEPPER_X_POS: AtomicI32 = AtomicI32::new(0);
// Slot 4 and 5 positions sent by the Pi at boot for forbidden zone calculation.
// i32::MIN means "not configured" — servo blocking is disabled until set.
static SLOT4_POS: AtomicI32 = AtomicI32::new(i32::MIN);
static SLOT5_POS: AtomicI32 = AtomicI32::new(i32::MIN);
// Track current servo angle (0-180°). Starts at 180° (safe/closed).
static CURRENT_SERVO_ANGLE: AtomicI32 = AtomicI32::new(180);
// Track cup presence state: 1 = present, 0 = absent
static CUP_PRESENT: AtomicI32 = AtomicI32::new(0);

#[esp_rtos::main]
async fn main(spawner: Spawner) {
    esp_println::logger::init_logger_from_env();

    let config = esp_hal::Config::default().with_cpu_clock(CpuClock::max());
    let peripherals = esp_hal::init(config);
    esp_alloc::heap_allocator!(size: 72 * 1024);

    let timg0 = esp_hal::timer::timg::TimerGroup::new(peripherals.TIMG0);
    let sw_interrupt =
        esp_hal::interrupt::software::SoftwareInterruptControl::new(peripherals.SW_INTERRUPT);
    esp_rtos::start(timg0.timer0, sw_interrupt.software_interrupt0);

    info!("Startup...\r");

    let (usb_rx, _) = UsbSerialJtag::new(peripherals.USB_DEVICE)
        .into_async()
        .split();
    spawner.must_spawn(tasks::serial::serial_reader(
        usb_rx,
        &CMD_CHANNEL,
        STOP_CHANNEL.publisher().unwrap(),
    ));

    let cup_sensor = Input::new(
        peripherals.GPIO2,
        InputConfig::default().with_pull(esp_hal::gpio::Pull::Up),
    );
    spawner.must_spawn(tasks::cup_presence_monitor(cup_sensor));

    let tx_cfg = rmt::TxChannelConfig {
        idle_output: true,
        idle_output_level: esp_hal::gpio::Level::Low,
        clk_divider: 40, // 1 microsecond tick (40 MHz / 40)
        memsize: 1,
        ..Default::default()
    };
    let mut rmt = rmt::Rmt::new(peripherals.RMT, Rate::from_mhz(40));
    let stepper_channel = rmt.channel(0, peripherals.GPIO20, tx_cfg);

    let mut stepper = Stepper::new(
        stepper_channel,
        Rate::from_hz(40_000_000 / 40),
        peripherals.GPIO21,
        false,
    );
    stepper.set_accel_speed(STEPPER_NORMAL_ACCEL_SPEED).unwrap();
    STEPPER_HOMING_ACCEL_SPEED
        .validate_for_stepper(&stepper)
        .unwrap();

    let end_switch = Input::new(
        peripherals.GPIO7,
        InputConfig::default().with_pull(esp_hal::gpio::Pull::Up),
    );
    spawner.must_spawn(tasks::stepper::stepper_task(
        stepper,
        end_switch,
        &STEPPER_CMD_SIG,
        STOP_CHANNEL.subscriber().unwrap(),
        spawner,
    ));

    spawner.must_spawn(tasks::route_cmd::route_cmd(tasks::route_cmd::HandleCmd {
        cmd_chan: &CMD_CHANNEL,
        stepper_sig: &STEPPER_CMD_SIG,
        stop_sub: STOP_CHANNEL.subscriber().unwrap(),
        servo_sig: &SERVO_CMD_SIG,
    }));

    spawner.must_spawn(tasks::servo::servo_task(
        &SERVO_CMD_SIG,
        STOP_CHANNEL.subscriber().unwrap(),
        peripherals.LEDC,
        peripherals.GPIO9,
    ));

    info!("Barbot HAT v{} running\r", env!("CARGO_PKG_VERSION"));
}

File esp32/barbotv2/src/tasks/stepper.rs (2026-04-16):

use core::sync::atomic::{AtomicBool, AtomicU8, Ordering};

use embassy_executor::Spawner;
use esp_hal::gpio::{Input, Level};
use futures::{FutureExt, select_biased};
use num_traits::Float;

use crate::cmd::{StepperCmd, StepperCmdSignal, StopCmd, StopCmdSub};
use crate::stepper::{self, Dir, Stepper};
use crate::utils::Signal;

#[derive(Debug)]
struct HomingState {
    homing_needed: bool,
    end_pos: i32,
}

impl HomingState {
    async fn home_stepper(
        &mut self,
        stepper: &mut Stepper<'static>,
        end_switch_sig: &'static Signal<()>,
        emergency_stop_sig: &'static Signal<()>,
    ) {
        end_switch_sig.reset();
        if END_SWITCH_ACTIVE.load(Ordering::SeqCst) {
            log::error!("Homing failed: end switch already active\r");
            return;
        }
        stepper.set_curr_pos(0);
        let mut res =
            move_to_end_switch(Dir::Negative, stepper, emergency_stop_sig, end_switch_sig).await;
        if !res {
            log::error!("Homing failed: could not reach end switch\r");
            return;
        }
        res = move_away_from_end_switch(Dir::Negative, stepper, emergency_stop_sig, end_switch_sig)
            .await;
        if !res {
            log::error!("Homing failed: could not move away from end switch\r");
            return;
        }
        log::info!(
            "Homing to start position successful ({} steps)\r",
            stepper.curr_pos().abs() / crate::MICROSTEPS as i32
        );
        stepper.set_curr_pos(0);
        crate::STEPPER_X_POS.store(0, Ordering::Relaxed);

        let mut res =
            move_to_end_switch(Dir::Positive, stepper, emergency_stop_sig, end_switch_sig).await;
        if !res {
            log::error!("Homing failed: could not reach end switch\r");
            return;
        }
        res = move_away_from_end_switch(Dir::Positive, stepper, emergency_stop_sig, end_switch_sig)
            .await;
        if !res {
            log::error!("Homing failed: could not move away from end switch\r");
            return;
        }
        self.end_pos = stepper.curr_pos();
        self.homing_needed = false;

        log::info!("Homing successful, end pos = {}\r", self.end_pos / crate::MICROSTEPS as i32);
    }
}

struct AtomicCellLevel(AtomicU8);
impl AtomicCellLevel {
    const fn new(level: Option<Level>) -> Self {
        let v = match level {
            Some(Level::Low) => 0,
            Some(Level::High) => 1,
            None => 2,
        };
        Self(AtomicU8::new(v))
    }

    fn get(&self) -> Option<Level> {
        match self.0.load(Ordering::SeqCst) {
            0 => Some(Level::Low),
            1 => Some(Level::High),
            _ => None,
        }
    }

    fn set(&self, level: Option<Level>) {
        let v = match level {
            Some(Level::Low) => 0,
            Some(Level::High) => 1,
            None => 2,
        };
        self.0.store(v, Ordering::SeqCst);
    }
}

static HOMING_MOVE_TARGET_LEVEL: AtomicCellLevel = AtomicCellLevel::new(None);
static END_SWITCH_ACTIVE: AtomicBool = AtomicBool::new(false);
#[embassy_executor::task]
async fn route_end_switch_trigger(
    mut end_switch: Input<'static>,
    stepper_stop_sig: &'static stepper::StopSignal,
    end_switch_sig: &'static Signal<()>,
    homing_move_target_level: &'static AtomicCellLevel,
) {
    let mut last_level = None;
    loop {
        // TODO: Debounce?
        end_switch.wait_for_any_edge().await;
        let level = end_switch.level();
        if let Some(l) = last_level
            && l == level
        {
            continue;
        }
        last_level = Some(level);

        if level == Level::Low {
            end_switch_sig.signal(());
            END_SWITCH_ACTIVE.store(true, Ordering::SeqCst);
        } else {
            END_SWITCH_ACTIVE.store(false, Ordering::SeqCst);
        }

        // If we are doing a homing move we want to gracefully stop when the end switch
        // has the set target level.
        let maybe_target_level = homing_move_target_level.get();
        match (maybe_target_level, level) {
            (Some(Level::High), Level::High) | (Some(Level::Low), Level::Low) => {
                stepper_stop_sig.signal(());
            }
            _ => (),
        }

        log::info!("End switch = {level:?}\r");
    }
}
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

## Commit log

2024-11-11 Add original arduino file
    this is unfortunately the old version which does not have a smooth
    acceleration of the servo motor. The improved version is gone.
    Only use it as a reference and do not upload it to the ESP32 mounted on the barbot!
    For testing, use a different ESP32 board and clip it to the barbot.
2024-12-18 Dummy statemachine created
    working state machine using common gcode notation. Sample code:
    X for position (1-12), Z for pressing duration (in ms)
    sample code:
    G1 X11 Z2500
    G28
    G1 X12 Z2000
    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
2024-12-18 renamed variables
    used "Sound" instead of pressing motor, because otherwise chatgpt always set Z as coordinate and not time.
    Rename variables for correctness
2024-12-18 Add ring control + homing
2024-12-18 Add README.md for ESP32
2024-12-20 Add retraction before Homing, and other fixes
2024-12-20 Remove test files
    # Conflicts:
    # esp32/serial_test/serial_test.ino
    # esp32/stepper_test/stepper_test.ino
2025-04-18 Start with PCB design
    [barbot_hat.kicad_pcb, barbot_hat.kicad_sch]
2025-04-22 Work on layout
    [barbot_hat.kicad_pcb, barbot_hat.kicad_sch, pump_motor.kicad_sch]
2025-04-22 Add stepper ref image to schematic
    [barbot_hat.kicad_pcb, barbot_hat.kicad_sch]
2025-04-23 Change power delivery, update logo
    [barbot_hat.kicad_pcb, barbot_hat.kicad_sch]
2025-04-23 Update front silk
    [barbot_hat.kicad_pcb]
2025-04-24 Update images and readme
    [barbot_hat.kicad_pcb]
2025-05-01 Add initial esp32 firmware setup
2025-05-03 Add gcode parsing, begin stepper control
2025-05-08 Implement stepper motor control
2025-05-20 Improve stepper, implement gcode commands
    Add crate `stepgen` as local module (copy-paste), to make changes in the
    future.
2025-09-10 Update pump motor
    [barbot_hat.kicad_sch, pump_motor.kicad_sch]
2025-12-14 Update dependencies, pin assignments
2025-12-14 Refactor, implement homing
2025-12-16 Upgrade to 2024 edition, refactor RMT driver
2025-12-16 Implement pump control, wait until emergency is cleared
2025-12-18 Lift motor, fixes, more commands
    [cmd.rs, main.rs, rmt.rs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]
2026-04-11 added heartbeat thread for the homepage
2026-04-14 Replace lift-motor with servo+scale; add ESP32 G-code serial driver in Python
    ESP32 firmware (barbotv2):
    - Replace LiftMotorCmd/task with ServoCmdSignal + servo_task (PWM, 0-180°)
    - Add HX711 scale task with Kalman filter, tare, calibrate, and autonomous fill (G4)
    - Update StepperCmd variants to carry optional AccelSpeedConfig per command
    - Add G3/G3.1/G3.2/G4 G-code commands; update G0/G0.1/G1 accordingly
    - Change microstepping 1/8 → 1/4 (MICROSTEPS=4); update RMT clk_divider 80→40
    - Move emergency-stop GPIO to GPIO2; servo on GPIO9; HX711 DATA/CLK on GPIO8/10
    - Pump task: duration_ms==0 now means immediate stop
    Python (python_script2):
    - Add EspSerial: thread-safe serial driver with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
    [cmd.rs, config.py, hardware.py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]
2026-04-14 neopixel: serial feedback for unknown commands; -bri command for LED brightness
    - SerialParser::tryParse now returns true for all non-empty input (including
    invalid), so the Invalid branch in main.cpp is no longer dead code
    - Unknown commands print an ERR message with the full command list instead of
    being silently dropped
    - Add -bri <0-255> command to set LED strip brightness at runtime via
    LedStripController::setBrightness() / FastLED.setBrightness()
    - Update startup help text to include -bri
    [LedStripController.cpp, main.cpp]
2026-04-14 Add Teach Slots menu for physically calibrating cart positions
    HardwareConfig:
    - Add set_slot_position(slot, steps) and save() to write back to hardware_config.json
    LCD menu:
    - Maintenance → Teach Slots: lists all 12 slots with their current saved step value
    - Selecting a slot enters 'teach' mode: jog wheel adjusts target (slow=1 step,
    fast=100 steps), press → confirm → cart moves to target → position saved to JSON
    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
2026-04-14 barbotv2: lower default stepper max speed 4000 → 3800 full steps/s
2026-04-14 barbot_web: slot buttons for stepper, open/close presets for servo
    Stepper section:
    - /api/slots endpoint reads hardware_config.json live
    - Spirit slots (1-8) and Mixer slots (A-D) rendered as clickable buttons
    showing slot label + saved step position; clicking sends G0 X{pos}
    - Reload button to refresh positions after teaching
    - Unset slots shown dimmed with '?' instead of crashing
    Servo section:
    - Keep existing slider for manual control
    - Add Open / Close angle inputs (number fields, 0-180°) with dedicated buttons
    - Clicking Open/Close also syncs the slider to the chosen angle
2026-04-14 teach mode: move live on knob rotation, auto-enter after initial move
    - _enter_teach: show working screen, move cart to saved position first,
    then automatically switch to teach mode (no user press needed)
    - _on_rotate (teach): send G0 immediately on every rotation outside the
    lock so the cart tracks the knob in real time
    - _do_teach_save: removed redundant move_x — cart is already at target
    position from live jogging, just persist to hardware_config.json
2026-04-14 teach mode: debounce knob rotation — send G0 only when knob stops
    Replace per-detent G0 spam with a 120ms debounce timer. Each rotation
    event cancels the previous pending timer and schedules a new one, so
    only the final resting position is ever sent to the ESP32. Eliminates
    the command queue buildup that caused the cart to lag far behind the
    knob.
    [lcd_menu.py]
2026-04-14 barbotv2: reverse pump pin order (0↔3, 1↔2)
    Pump 0 → GPIO3, 1 → GPIO4, 2 → GPIO5, 3 → GPIO6
    [main.rs]
2026-04-14 config: use stable by-id symlink for barbotv2 serial port
    ttyACMx re-enumerates on every replug/reboot. The by-id symlink is
    tied to the device's USB serial number and never changes.
2026-04-14 fix: teach debounce 250ms + robust scale weight parsing
    - lcd_menu: increase teach jog debounce 120ms → 250ms so slow knob
    rotation (~150ms/detent) no longer fires a G0 per step
    - hardware: add 'raw:' to all wait_for() weight patterns so the sync
    barrier matches even when the ESP32 log prefix mangles 'Weight:' into
    'INFOight:' or similar
    - hardware: replace fragile split() weight parsing with regex (_parse_grams)
    that handles any log prefix and falls back to bare float+g pattern
    - hardware: import re
    [hardware.py, lcd_menu.py]
2026-04-14 feat: add live weight display to Scale card in web UI
    Shows a large prominent readout (grams + raw ADC) that updates
    automatically whenever a G3 response arrives in the serial stream.
    Tare (G3.1) resets the display to 0.00g.
2026-04-14 fix: emit 'Move done' after stepper move, remove spurious G3 sync
    route_cmd prints INFO Move done after each GoTo/GoToRangeFact completes
    (not after homing, which already has its own 'Homing successful' response).
    Python move_x() waits for 'Move done' instead of sending a G3 scale read
    as a sync barrier — so moving no longer triggers a weight reading.
    _sync() (G3-based) is kept for compound sequences in dispense_spirit /
    dispense_mixer where servo + pump + wait commands are pipelined and we
    genuinely want to know all of them are finished.
    [hardware.py, route_cmd.rs]
2026-04-14 debug: add G3.9 scale diagnostic command
    G3.9 [N{count}] reads N raw HX711 samples (default 10) and prints:
    - DOUT level before waiting (HIGH=not ready, LOW=ready or floating)
    - Per-sample: wait_data_ready time (ms) + raw 24-bit signed value
    If wait time is ~0ms and raw is always 0, the DATA pin is floating LOW.
    If wait time is ~100ms and raw varies, the chip is working but needs calibration.
2026-04-14 fix: swap HX711 pins — DATA→GPIO10, CLK→GPIO8
    [main.rs]
2026-04-14 revert: restore HX711 pins — DATA=GPIO8, CLK=GPIO10
    [main.rs]
2026-04-14 fix: enable pull-up on HX711 DATA pin (GPIO8)
    DOUT idles HIGH and only goes LOW when data is ready.
    Without a pull-up the pin floats LOW, giving a false 'detected'
    on startup and reading all-zero bits every time.
    [main.rs]
2026-04-16 feat: cup confirmation countdown, drink-ready animations, error retry UI
    Key changes:
    - Cup detection: ESP32 emits initial cup state on boot; Pi syncs on startup
    - Cup confirmation: 6s countdown with slow→fast green flash and 7-seg digit
    - Drink-ready: green ring pulse + cycling bar/U animations (comet/chase/scanner/rainbow)
    - 7-seg escalating blink: slow→fast over 5s cycles during pickup wait
    - After 60s uncollected: full red strobe everything until cup taken
    - Error screen: rotate to select RETRY/CANCEL, press to confirm
    - RETRY: reruns only the mixer part (spirits already dispensed)
    - Scale: pump rate window doubled to 30 samples
    - New LED effects: GREEN_FLASH_SLOW, GREEN_FLASH_FAST,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
    [DisplayController.cpp, LedStripController.cpp, cmd.rs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]
2026-04-16 feat: add scale calibration to LCD service menu
    - New 'Calibrate Scale' item under Settings > Hardware > Scale
    - Prompts for known weight (rotate to set grams, press confirm)
    - Tares scale then sends G3.2, saves factor to hardware_config.json
    - Factor is restored via G3.3 on every boot so reflashing doesn't lose it
    - Also adds calibrate_scale() method to HardwareInterface
    [hardware.py, lcd_menu.py]
2026-04-26 fix retry and remove that only mixers are retried and the entire drink will be made new
    [lcd_menu.py, orders.py]
2026-04-26 remove pin lock
2026-04-26 save pause before moving servo
2026-04-27 fix led position and slow down homing
    [lcd.py, main.rs]
2026-04-27 homing timeout to 240s
2026-04-27 increase homing timeout again
2026-04-28 add reverse and fix retry
    [main.cpp, orders.py]
2026-04-28 replace cup if failed
    [hardware.py, lcd_menu.py, orders.py]
2026-04-28 replace cup if failed 2
    [orders.py]
2026-05-05 Add draft for modular architecture and proto board
    [proto_board.kicad_pcb, proto_board.kicad_sch]
2026-05-05 Add solder pads to ribbon cable
    [proto_board.kicad_pcb, proto_board.kicad_sch]
2026-05-05 Fix schematic
    [proto_board.kicad_pcb, proto_board.kicad_sch]
